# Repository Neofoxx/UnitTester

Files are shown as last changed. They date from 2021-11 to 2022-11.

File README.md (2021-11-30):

# UnitTester
A rack mounted piece of gear for testing chips

#### Why
Always wanted some rack-mount piece of gear based on the DIN 41612 standard. This is slightly modified.
Also, want to test the complete PIC32 toolchain without plugging and replugging the programmer a thousand times.

#### When
Soon.

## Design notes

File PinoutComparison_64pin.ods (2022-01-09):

Comparison of 64-pin PIC32s, that should (ideally) all fit on one board
Special features: |  |  | VCAP | 3v3 | GND | USB | ICSP | JTAG | ICSP+JTAG
Not shown – 5V tolerance of pins
PIN \ NAME | Common to all | PIC32MX170F512H | PIC32MX250F256H and PIC32MX570F512H | PIC32MX340F256H | PIC32MX440F256H | PIC32MX350F256H | PIC32MX450F256H | PIC32MX534F064H | PIC32MX675F256H | PIC32MX775F256H | PIC32MZ2048EFK064 (just checking)
1 |  | AN22/RPE5/PMD5/RE5 | AN22/RPE5/PMD5/RE5 | PMD5/RE5 | PMD5/RE5 | AN22/RPE5/PMD5/RE5 | AN22/RPE5/PMD5/RE5 | PMD5/RE5 | ETXEN/PMD5/RE5 | ETXEN/PMD5/RE5 | AN17/ETXEN/RPE5/PMD5/RE5
2 |  | AN23/PMD6/RE6 | AN23/PMD6/RE6 | PMD6/RE6 | PMD6/RE6 | AN23/PMD6/RE6 | AN23/PMD6/RE6 | PMD6/RE6 | ETXD0/PMD6/RE6 | ETXD0/PMD6/RE6 | AN16/ETXD0/PMD6/RE6
3 |  | AN27/PMD7/RE7 | AN27/PMD7/RE7 | PMD7/RE7 | PMD7/RE7 | AN27/PMD7/RE7 | AN27/PMD7/RE7 | PMD7/RE7 | ETXD1/PMD7/RE7 | ETXD1/PMD7/RE7 | AN15/ETXD1/PMD7/RE7
4 |  | AN16/C1IND/RPG6/SCK2/PMA5/RG6 | AN16/C1IND/RPG6/SCK2/PMA5/RG6 | SCK2/PMA5/CN8/RG6 | SCK2/PMA5/CN8/RG6 | AN16/C1IND/RPG6/SCK2/PMA5/RG6 | AN16/C1IND/RPG6/SCK2/PMA5/RG6 | SCK2/U6TX/U3RTS/PMA5/CN8/RG6 | SCK2/U6TX/U3RTS/PMA5/CN8/RG6 | SCK2/U6TX/U3RTS/PMA5/CN8/RG6 | AN14/C1IND/RPG6/SCK2/PMA5/RG6
5 |  | AN17/C1INC/RPG7/PMA4/RG7 | AN17/C1INC/RPG7/PMA4/RG7 | SDI2/PMA4/CN9/RG7 | SDI2/PMA4/CN9/RG7 | AN17/C1INC/RPG7/PMA4/RG7 | AN17/C1INC/RPG7/PMA4/RG7 | SDA4/SDI2/U3RX/PMA4/CN9/RG7 | SDA4/SDI2/U3RX/PMA4/CN9/RG7 | SDA4/SDI2/U3RX/PMA4/CN9/RG7 | AN13/C1INC/RPG7/SDA4/PMA4/RG7
6 |  | AN18/C2IND/RPG8/PMA3/RG8 | AN18/C2IND/RPG8/PMA3/RG8 | SDO2/PMA3/CN10/RG8 | SDO2/PMA3/CN10/RG8 | AN18/C2IND/RPG8/PMA3/RG8 | AN18/C2IND/RPG8/PMA3/RG8 | SCL4/SDO2/U3TX/PMA3/CN10/RG8 | SCL4/SDO2/U3TX/PMA3/CN10/RG8 | SCL4/SDO2/U3TX/PMA3/CN10/RG8 | AN12/C2IND/RPG8/SCL4/PM3/RG8
7 | MCLR | MCLR | MCLR | MCLR | MCLR | MCLR | MCLR | MCLR | MCLR | MCLR | VSS
8 |  | AN19/C2INC/RPG9/PMA2/RG9 | AN19/C2INC/RPG9/PMA2/RG9 | SS2/PMA2/CN11/RG9 | SS2/PMA2/CN11/RG9 | AN19/C2INC/RPG9/PMA2/RG9 | AN19/C2INC/RPG9/PMA2/RG9 | SS2 /U6RX/U3CTS/PMA2/CN11/RG9 | SS2/U6RX/U3CTS/PMA2/CN11/RG9 | SS2/U6RX/U3CTS/PMA2/CN11/RG9 | VDD
9 | VSS | VSS | VSS | VSS | VSS | VSS | VSS | VSS | VSS | VSS | MCLR
10 | VDD | VDD | VDD | VDD | VDD | VDD | VDD | VDD | VDD | VDD | AN11/C2INC/RPG9/PMA2/RG9
11 |  | AN5/C1INA/RPB5/RB5 | AN5/C1INA/RPB5/VBUSON/RB5 | AN5/C1IN+/CN7/RB5 | AN5/C1IN+/VBUSON/CN7/RB5 | AN5/C1INA/RPB5/RB5 | AN5/C1INA/RPB5/VBUSON/RB5 | AN5/C1IN+/VBUSON/CN7/RB5 | AN5/C1IN+/VBUSON/CN7/RB5 | AN5/C1IN+/VBUSON/CN7/RB5 | AN45/C1INA/RPB5/RB5
12 |  | AN4/C1INB/RB4 | AN4/C1INB/RB4 | AN4/C1IN-/CN6/RB4 | AN4/C1IN-/CN6/RB4 | AN4/C1INB/RB4 | AN4/C1INB/RB4 | AN4/C1IN-/CN6/RB4 | AN4/C1IN-/CN6/RB4 | AN4/C1IN-/CN6/RB4 | AN4/C1INB/RB4
13 |  | PGED3/AN3/C2INA/RPB3/RB3 | PGED3/AN3/C2INA/RPB3/RB3 | AN3/C2IN+/CN5/RB3 | AN3/C2IN+/CN5/RB3 | PGED3/AN3/C2INA/RPB3/RB3 | PGED3/AN3/C2INA/RPB3/RB3 | AN3/C2IN+/CN5/RB3 | AN3/C2IN+/CN5/RB3 | AN3/C2IN+/CN5/RB3 | AN3/C2INA/RPB3/RB3
14 |  | PGEC3/AN2/CTCMP/C2INB/RPB2/CTED13/RB2 | PGEC3/AN2/CTCMP/C2INB/RPB2/CTED13/RB2 | AN2/C2IN-/SS1/CN4/RB2 | AN2/C2IN-/CN4/RB2 | PGEC3/AN2/C2INB/RPB2/CTED13/RB2 | PGEC3/AN2/C2INB/RPB2/CTED13/RB2 | AN2/C2IN-/CN4/RB2 | AN2/C2IN-/CN4/RB2 | AN2/C2IN-/CN4/RB2 | AN2/C2INB/RPB2/RB2
15 |  | PGEC1/VREF-/AN1/RPB1/CTED12/RB1 | PGEC1/VREF-/AN1/RPB1/CTED12/RB1 | PGEC1/AN1/VREF-/CVREF-/CN3/RB1 | PGEC1/AN1/VREF-/CVREF-/CN3/RB1 | PGEC1/VREF-/CVREF-/AN1/RPB1/CTED12/RB1 | PGEC1/VREF-/CVREF-/AN1/RPB1/CTED12/RB1 | PGEC1/AN1/VREF-/CVREF-/CN3/RB1 | PGEC1/AN1/VREF-/CVREF-/CN3/RB1 | PGEC1/AN1/VREF-/CVREF-/CN3/RB1 | PGEC1/VREF-/CVREF-/AN1/RPB1/RB1
16 |  | PGED1/VREF+/AN0/RPB0/PMA6/RB0 | PGED1/VREF+/AN0/RPB0/PMA6/RB0 | PGED1/AN0/VREF+/CVREF+/PMA6/CN2/RB0 | PGED1/AN0/VREF+/CVREF+/PMA6/CN2/RB0 | PGED1/VREF+/CVREF+/AN0/RPB0/PMA6/RB0 | PGED1/VREF+/CVREF+/AN0/RPB0/PMA6/RB0 | PGED1/AN0/VREF+/CVREF+/PMA6/CN2/RB0 | PGED1/AN0/VREF+/CVREF+/PMA6/CN2/RB0 | PGED1/AN0/VREF+/CVREF+/PMA6/CN2/RB0 | PGED1/VREF+/CVREF+/AN0/RPB0/PMA6/RB0
17 | PGEC2 | PGEC2/AN6/RPB6/RB6 | PGEC2/AN6/RPB6/RB6 | PGEC2/AN6/OCFA/RB6 | PGEC2/AN6/OCFA/RB6 | PGEC2/AN6/RPB6/RB6 | PGEC2/AN6/RPB6/RB6 | PGEC2/AN6/OCFA/RB6 | PGEC2/AN6/OCFA/RB6 | PGEC2/AN6/OCFA/RB6 | PGEC2/AN46/RPB6/RB6
18 | PGED2 | PGED2/AN7/RPB7/CTED3/RB7 | PGED2/AN7/RPB7/CTED3/RB7 | PGED2/AN7/RB7 | PGED2/AN7/RB7 | PGED2/AN7/RPB7/CTED3//RB7 | PGED2/AN7/RPB7/CTED3//RB7 | PGED2/AN7/RB7 | PGED2/AN7/RB7 | PGED2/AN7/RB7 | PGED2/AN47/RPB7/RB7
19 | AVDD | AVDD | AVDD | AVDD | AVDD | AVDD | AVDD | AVDD | AVDD | AVDD | AVDD
20 | AVSS | AVSS | AVSS | AVSS | AVSS | AVSS | AVSS | AVSS | AVSS | AVSS | AVSS
21 |  | AN8/RPB8/CTED10/RB8 | AN8/RPB8/CTED10/RB8 | AN8/U2CTS/C1OUT/RB8 | AN8/U2CTS/C1OUT/RB8 | AN8/RPB8/CTED10//RB8 | AN8/RPB8/CTED10//RB8 | AN8/SS4/U5RX/U2CTS/C1OUT/RB8 | AN8/SS4/U5RX/U2CTS/C1OUT/RB8 | AN8/C2TX(2)/SS4/U5RX/U2CTS/C1OUT/RB8 | AN48/RPB8/PMA10/RB8
22 |  | AN9/RPB9/CTED4/PMA7/RB9 | AN9/RPB9/CTED4/PMA7/RB9 | AN9/C2OUT/PMA7/RB9 | AN9/C2OUT/PMA7/RB9 | AN9/RPB9/CTED4/PMA7/RB9 | AN9/RPB9/CTED4/PMA7/RB9 | AN9/C2OUT/PMA7/RB9 | AN9/C2OUT/PMA7/RB9 | AN9/C2OUT/PMA7/RB9 | AN49/RPB9/PMA7/RB9
23 | TMS | TMS/CVREFOUT/AN10/RPB10/CTED11/PMA13/RB10 | TMS/CVREFOUT/AN10/RPB10/CTED11/PMA13/RB10 | TMS/AN10/CVREFOUT/PMA13/RB10 | TMS/AN10/CVREFOUT/PMA13/RB10 | TMS/CVREFOUT/AN10/RPB10/CTED11//PMA13/RB10 | TMS/CVREFOUT/AN10/RPB10/CTED11//PMA13/RB10 | TMS/AN10/CVREFOUT/PMA13/RB10 | TMS/AN10/CVREFOUT/PMA13/RB10 | TMS/AN10/CVREFOUT/PMA13/RB10 | TMS/CVREFOUT/AN5/RPB10/PMA13/RB10
24 | TDO | TDO/AN11/PMA12/RB11 | TDO/AN11/PMA12/RB11 | TDO/AN11/PMA12/RB11 | TDO/AN11/PMA12//RB11 | TDO/AN11/PMA12/RB11 | TDO/AN11/PMA12/RB11 | TDO/AN11/PMA12/RB11 | TDO/AN11/PMA12/RB11 | TDO/AN11/PMA12/RB11 | TDO/AN6/PMA12/RB11
25 | VSS | VSS | VSS | VSS | VSS | VSS | VSS | VSS | VSS | VSS | VSS
26 | VDD | VDD | VDD | VDD | VDD | VDD | VDD | VDD | VDD | VDD | VDD
27 | TCK | TCK/AN12/PMA11/RB12 | TCK/AN12/PMA11/RB12 | TCK/AN12/PMA11/RB12 | TCK/AN12/PMA11/RB12 | TCK/AN12/PMA11/RB12 | TCK/AN12/PMA11/RB12 | TCK/AN12/PMA11/RB12 | TCK/AN12/PMA11/RB12 | TCK/AN12/PMA11/RB12 | TCK/AN7/PMA11/RB12
28 | TDI | TDI/AN13/PMA10/RB13 | TDI/AN13/PMA10/RB13 | TDI/AN13/PMA10/RB13 | TDI/AN13/PMA10/RB13 | TDI/AN13/PMA10/RB13 | TDI/AN13/PMA10/RB13 | TDI/AN13/PMA10/RB13 | TDI/AN13/PMA10/RB13 | TDI/AN13/PMA10/RB13 | TDI/AN8/RB13
29 |  | AN14/RPB14/SCK3/CTED5/PMA1/RB14 | AN14/RPB14/SCK3/CTED5/PMA1/RB14 | AN14/U2RTS/PMALH/PMA1/RB14 | AN14/U2RTS/PMALH/PMA1/RB14 | AN14/RPB14/CTED5/PMA1/RB14 | AN14/RPB14/CTED5/PMA1/RB14 | AN14/SCK4/U5TX/U2RTS/PMALH/PMA1/RB14 | AN14/SCK4/U5TX/U2RTS/PMALH/PMA1/RB14 6 | AN14/C2RX(2)/SCK4/U5TX/U2RTS/PMALH/PMA1/RB14 | AN9/RPB14/SCK3/PMA1/RB14
30 |  | AN15/RPB15/OCFB/CTED6/PMA0/RB15 | AN15/RPB15/OCFB/CTED6/PMA0/RB15 | AN15/OCFB/PMALL/PMA0/CN12/RB15 | AN15/OCFB/PMALL/PMA0/CN12/RB15 | AN15/RPB15/OCFB/CTED6/PMA0/RB15 | AN15/RPB15/OCFB/CTED6/PMA0/RB15 | AN15/OCFB/PMALL/PMA0/CN12/RB15 | AN15/EMDC/AEMDC/OCFB/PMALL/PMA0/CN12/RB15 | AN15/EMDC/AEMDC/OCFB/PMALL/PMA0/CN12/RB15 | AN10/EMDC/AEMDC/RPB15/OCFB/PMA0/RB15
31 | U2RX | RPF4/SDA2/PMA9/RF4 | RPF4/SDA2/PMA9/RF4 | SDA2/U2RX/PMA9/CN17/RF4 | SDA2/U2RX/PMA9/CN17/RF4 | RPF4/SDA2/PMA9/RF4 | RPF4/SDA2/PMA9/RF4 | AC1TX/SDA5/SDI4/U2RX/PMA9/CN17/RF4 | SDA5/SDI4/U2RX/PMA9/CN17/RF4 | AC1TX/SDA5/SDI4/U2RX/PMA9/CN17/RF4 | OSC1/CLKI/RC12
32 | U2TX | RPF5/SCL2/PMA8/RF5 | RPF5/SCL2/PMA8/RF5 | SCL2/U2TX/PMA8/CN18/RF5 | SCL2/U2TX/PMA8/CN18/RF5 | RPF5/SCL2/PMA8/RF5 | RPF5/SCL2/PMA8/RF5 | AC1RX/SCL5/SDO4/U2TX/PMA8/CN18/RF5 | SCL5/SDO4/U2TX/PMA8/CN18/RF5 | AC1RX/SCL5/SDO4/U2TX/PMA8/CN18/RF5 | OSC2/CLKO/RC15
33 |  | RPF3/RF3 | USBID/RPF3/RF3 | U1TX/SDO1/RF3 | USBID/RF3 | RPF3/RF3 | USBID/RF3 | USBID/RF3 | USBID/RF3 | USBID/RF3 | VBUS
34 | 5V VIA VOLTAGE DIVIDER | RPF2/RF2 | VBUS | U1RX/SDI1/RF2 | VBUS | RPF2/RF2 | VBUS | VBUS | VBUS | VBUS | VUSB3V3
35 | VDD VIA RESISTOR | RPF6/SCK1/INT0/RF6 | VUSB3V3 | U1RTS/SCK1/INT0/RF6 | VUSB | RPF6/SCK1/INT0/RF6 | VUSB3V3 | VUSB3V3 | VUSB3V3 | VUSB3V3 | VSS
36 | D- | SDA1/RG3 | D- | SDA1/RG3 | D-/RG3 | SDA1/RG3 | D- | D-/RG3 | D-/RG3 | D-/RG3 | D-
37 | D+ | SCL1/RG2 | D+ | SCL1/RG2 | D+/RG2 | SCL1/RG2 | D+ | D+/RG2 | D+/RG2 | D+/RG2 | D+
38 | VDD | VDD | VDD | VDD | VDD | VDD | VDD | VDD | VDD | VDD | RPF3/USBID/RF3
39 | Crystal | OSC1/CLKI/RC12 | OSC1/CLKI/RC12 | OSC1/CLKI/RC12 | OSC1/CLKI/RC12 | OSC1/CLKI/RC12 | OSC1/CLKI/RC12 | OSC1/CLKI/RC12 | OSC1/CLKI/RC12 | OSC1/CLKI/RC12 | VDD
40 | Crystal | OSC2/CLKO/RC15 | OSC2/CLKO/RC15 | OSC2/CLKO/RC15 | OSC2/CLKO/RC15 | OSC2/CLKO/RC15 | OSC2/CLKO/RC15 | OSC2/CLKO/RC15 | OSC2/CLKO/RC15 | OSC2/CLKO/RC15 | VSS
41 | VSS | VSS | VSS | VSS | VSS | VSS | VSS | VSS | VSS | VSS | RPF4/SDA5/PMA9/RF4
42 |  | RPD8/RTCC/RD8 | RPD8/RTCC/RD8 | RTCC/IC1/INT1/RD8 | RTCC/IC1/INT1/RD8 | RPD8/RTCC/RD8 | RPD8/RTCC/RD8 | RTCC/IC1/INT1/RD8 | RTCC/AERXD1/ETXD3/IC1/INT1/RD8 | RTCC/AERXD1/ETXD3/IC1/INT1/RD8 | RPF5/SCL5/PMA8/RF5
43 |  | RPD9/RD9 | RPD9/SDA1/RD9 | U1CTS/IC2/INT2/RD9 | U1CTS/SDA1/IC2/INT2/RD9 | RPD9/RD9 | RPD9/SDA1/RD9 | SS3/U4RX/U1CTS/SDA1/IC2/INT2/RD9 | AERXD0/ETXD2/SS3/U4RX/U1CTS/SDA1/IC2/INT2/RD9 | AERXD0/ETXD2/SS3/U4RX/U1CTS/SDA1/IC2/INT2/RD9 | AERXD0/ETXD2/RPD9/SDA1/PMCS2/PMA15/RD9
44 |  | RPD10/PMA15/RD10 | RPD10/SCL1/PMA15/RD10 | IC3/PMCS2/PMA15/INT3/RD10 | SCL1/IC3/PMCS2/PMA15/INT3/RD10 | RPD10/PMCS2/RD10 | RPD10/SCL1/PMCS2/RD10 | SCL1/IC3/PMCS2/PMA15/INT3/RD10 | ECOL/AECRSDV/SCL1/IC3/PMCS2/PMA15/INT3/RD10 | ECOL/AECRSDV/SCL1/IC3/PMCS2/PMA15/INT3/RD10 | ECOL/RPD10/SCL1/SCK4/RD10
45 |  | RPD11/PMA14/RD11 | RPD11/PMA14/RD11 | IC4/PMCS1/PMA14/INT4/RD11 | IC4/PMCS1/PMA14/INT4/RD11 | RPD11/PMCS1/RD11 | RPD11/PMCS1/RD11 | IC4/PMCS1/PMA14/INT4/RD11 | ECRS/AEREFCLK/IC4/PMCS1/PMA14/INT4/RD11 | ECRS/AEREFCLK/IC4/PMCS1/PMA14/INT4/RD11 | AERXCLK/AEREFCLK/ECRS/RPD11/PMCS1/PMA14/RD11
46 | LED | RPD0/RD0 | RPD0/INT0/RD0 | OC1/RD0 | OC1/INT0/RD0 | RPD0/RD0 | RPD0/INT0/RD0 | OC1/INT0/RD0 | OC1/INT0/RD0 | OC1/INT0/RD0 | AERXD1/ETXD3/RPD0/RTCC/INT0/RD0
47 | Crystal | SOSCI/RPC13/RC13 | SOSCI/RPC13/RC13 | SOSCI/CN1/RC13 | SOSCI/CN1/RC13 | SOSCI/RPC13/RC13 | SOSCI/RPC13/RC13 | SOSCI/CN1/RC13 | SOSCI/CN1/RC13 | SOSCI/CN1/RC13 | SOSCI/RPC13/RC13
48 | Crystal | SOSCO/RPC14/T1CK/RC14 | SOSCO/RPC14/T1CK/RC14 | SOSCO/T1CK/CN0/RC14 | SOSCO/T1CK/CN0/RC14 | SOSCO/RPC14/T1CK/RC14 | SOSCO/RPC14/T1CK/RC14 | SOSCO/T1CK/CN0/RC14 | SOSCO/T1CK/CN0/RC14 | SOSCO/T1CK/CN0/RC14 | SOSCO/RPC14/T1CK/RC14
49 |  | AN24/RPD1/RD1 | AN24/RPD1/RD1 | OC2/RD1 | U1RTS/OC2/RD1 | AN24/RPD1/RD1 | AN24/RPD1/RD1 | SCK3/U4TX/U1RTS/OC2/RD1 | EMDIO/AEMDIO/SCK3/U4TX/U1RTS/OC2/RD1 | EMDIO/AEMDIO/SCK3/U4TX/U1RTS/OC2/RD1 | EMDIO/AEMDIO/RPD1/SCK1/RD1
50 |  | AN25/RPD2/RD2 | AN25/RPD2/SCK1/RD2 | OC3/RD2 | U1RX/OC3/RD2 | AN25/RPD2/RD2 | AN25/RPD2/SCK1/RD2 | SDA3/SDI3/U1RX/OC3/RD2 | SDA3/SDI3/U1RX/OC3/RD2 | SDA3/SDI3/U1RX/OC3/RD2 | ETXERR/AETXEN/RPD2/SDA3/RD2
51 |  | AN26/C3IND/RPD3/RD3 | AN26/C3IND/RPD3/RD3 | OC4/RD3 | U1TX/OC4/RD3 | AN26/RPD3/RD3 | AN26/RPD3/RD3 | SCL3/SDO3/U1TX/OC4/RD3 | SCL3/SDO3/U1TX/OC4/RD3 | SCL3/SDO3/U1TX/OC4/RD3 | AERXERR/ETXCLK/RPD3/SCL3/RD3
52 | BUTTON | RPD4/PMWR/RD4 | RPD4/PMWR/RD4 | OC5/IC5/PMWR/CN13/RD4 | OC5/IC5/PMWR/CN13/RD4 | RPD4/PMWR/RD4 | RPD4/PMWR/RD4 | OC5/IC5/PMWR/CN13/RD4 | OC5/IC5/PMWR/CN13/RD4 | OC5/IC5/PMWR/CN13/RD4 | SQICS0/RPD4/PMWR/RD4
53 |  | RPD5/PMRD/RD5 | RPD5/PMRD/RD5 | PMRD/CN14/RD5 | PMRD/CN14/RD5 | RPD5/PMRD/RD5 | RPD5/PMRD/RD5 | PMRD/CN14/RD5 | PMRD/CN14/RD5 | PMRD/CN14/RD5 | SQICS1/RPD5/PMRD/RD5
54 |  | C3INC/RD6 | C3INC/RD6 | CN15/RD6 | CN15/RD6 | RD6 | RD6 | CN15/RD6 | AETXEN/ETXERR/CN15/RD6 | AETXEN/ETXERR/CN15/RD6 | VDD
55 |  | C3INB/RD7 | C3INB/RD7 | CN16/RD7 | CN16/RD7 | RD7 | RD7 | CN16/RD7 | ETXCLK/AERXERR/CN16/RD7 | ETXCLK/AERXERR/CN16/RD7 | VSS
56 | VCAP | VCAP | VCAP | VCAP/VCORE | VCAP/VCORE | VCAP | VCAP | VCAP | VCAP | VCAP | ERXD3/AETXD1/RPF0/RF0
57 | VDD | VDD | VDD | ENVREG | ENVREG | VDD | VDD | VDD | VDD | VDD | TRCLK/SQICLK/ERXD2/AETXD0/RPF1/RF1
58 |  | C3INA/RPF0/RF0 | C3INA/RPF0/RF0 | RF0 | RF0 | RPF0/RF0 | RPF0/RF0 | C1RX/RF0 | AETXD1/ERXD3/RF0 | C1RX/AETXD1/ERXD3/RF0 | TRD0/SQID0/ERXD1/PMD0/RE0
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

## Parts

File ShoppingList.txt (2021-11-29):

- PIC12F615, HV verzija (vsaj 8, SOIC)
- Refill kondenzatorjev

* PIC32MX274F256D (PIC32MX275F256D is not available (with VBAT), MX175 ditto)

* = variants with USB
+ = variants with CAN
Support list
* PIC32MM GPL - done

* PIC32MM GPM - done

* PIC32MX 1/2*/5+
-> PIC32MX 1/2 should be done
-> PIC32MX 5 should be done, was tested with a little gumstix board from mikroelektronika

* PIC32MX 1/2* XLP - NOT DONE, NOT TESTED

* PIC32MX 3/4*
- Should be done, but there are some differences between say 340 and 350.
- Warrants another look

* PIC32MX 5x/6*/7+ (yo wtf) - shold be done
- Series 6&7 weren't tested, 5 should be in the above

* PIC32MK GP/MC
- Work continuing on it. There are differences in chips, but the peripherals are the same
- Differences are dual-banks of flash for example.

* PIC32MZ EF
- Should be working

* PIC32MZ DA
- Never tried, TODO

* PIC32MZ EC
- The abandoned platform. Purely out fo jest we should support it

* PIC32W (EZ in disguise)
- Should make compile just because.

Needed chips are then
MX5, MX6, MX7, MX1/2 XLP, MK?, MZ DA, MZ EC, MZ W.

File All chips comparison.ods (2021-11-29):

No. | Family | Part name | Pins | Package | Boot flash (kB) | Flash (kB) | RAM (kB) | Supported by toolchain | Debugging? | Own? | Notes
1 | PIC32MM GPL | PIC32MM0016GPL020 | 20 | SSOP/QFN | 5.75 | 16 | 4 | YES (needs procdefs) | NO |  | GPL family is fully supported
2 | PIC32MM GPL | PIC32MM0032GPL020 | 20 | SSOP/QFN | 5.75 | 32 | 8 | YES (needs procdefs) | NO
3 | PIC32MM GPL | PIC32MM0064GPL020 | 20 | SSOP/QFN | 5.75 | 64 | 8 | YES (needs procdefs) | NO | YES
4 | PIC32MM GPL | PIC32MM0016GPL028 | 28 | SSOP/SOIC/QFN/UQFN | 5.75 | 16 | 4 | YES (needs procdefs) | NO
5 | PIC32MM GPL | PIC32MM0032GPL028 | 28 | SSOP/SOIC/QFN/UQFN | 5.75 | 32 | 8 | YES (needs procdefs) | NO
6 | PIC32MM GPL | PIC32MM0064GPL028 | 28 | SSOP/SOIC/QFN/UQFN | 5.75 | 64 | 8 | YES (needs procdefs) | NO | YES
7 | PIC32MM GPL | PIC32MM0016GPL036 | 36/40 | VQFN/UQFN | 5.75 | 16 | 4 | YES (needs procdefs) | NO |  | 36-pin and 40-pin variants….
8 | PIC32MM GPL | PIC32MM0032GPL036 | 36/40 | VQFN/UQFN | 5.75 | 32 | 8 | YES (needs procdefs) | NO |  | 36-pin and 40-pin variants….
9 | PIC32MM GPL | PIC32MM0064GPL036 | 36/40 | VQFN/UQFN | 5.75 | 64 | 8 | YES | NO | YES | 36-pin and 40-pin variants….
10 | PIC32MM GPM | PIC32MM0064GPM028 | 28 | SSOP/QFN/UQFN | 5.75 | 64 | 16 | YES (needs procdefs) | NO |  | GPM family is fully supported
11 | PIC32MM GPM | PIC32MM0128GPM028 | 28 | SSOP/QFN/UQFN | 5.75 | 128 | 16 | YES (needs procdefs) | NO
12 | PIC32MM GPM | PIC32MM0256GPM028 | 28 | SSOP/QFN/UQFN | 5.75 | 256 | 32 | YES (needs procdefs) | NO | YES
13 | PIC32MM GPM | PIC32MM0064GPM036 | 36/40 | VQFN/UQFN | 5.75 | 64 | 16 | YES (needs procdefs) | NO |  | 36-pin and 40-pin variants….
14 | PIC32MM GPM | PIC32MM0128GPM036 | 36/40 | VQFN/UQFN | 5.75 | 128 | 16 | YES (needs procdefs) | NO |  | 36-pin and 40-pin variants….
15 | PIC32MM GPM | PIC32MM0256GPM036 | 36/40 | VQFN/UQFN | 5.75 | 256 | 32 | YES (needs procdefs) | NO | YES | 36-pin and 40-pin variants….
16 | PIC32MM GPM | PIC32MM0064GPM048 | 48 | UQFN/TQFP | 5.75 | 64 | 16 | YES (needs procdefs) | NO
17 | PIC32MM GPM | PIC32MM0128GPM048 | 48 | UQFN/TQFP | 5.75 | 128 | 16 | YES (needs procdefs) | NO
18 | PIC32MM GPM | PIC32MM0256GPM048 | 48 | UQFN/TQFP | 5.75 | 256 | 32 | YES (needs procdefs) | NO
19 | PIC32MM GPM | PIC32MM0064GPM064 | 64 | QFN/TQFP | 5.75 | 64 | 16 | YES (needs procdefs) | NO
20 | PIC32MM GPM | PIC32MM0128GPM064 | 64 | QFN/TQFP | 5.75 | 128 | 16 | YES (needs procdefs) | NO
21 | PIC32MM GPM | PIC32MM0256GPM064 | 64 | QFN/TQFP | 5.75 | 256 | 32 | YES (needs procdefs) | NO
22 | PIC32MX 1 | PIC32MX110F016B | 28 | SOIC,SSOP,SPDIP,QFN | 3 | 16 | 4 | YES (needs procdefs) | YES |  | PIC32MX 1 == PIC32MX 2, just without USB
23 | PIC32MX 1 | PIC32MX110F016C | 36 | VTLA | 3 | 16 | 4 | YES (needs procdefs) | YES
24 | PIC32MX 1 | PIC32MX110F016D | 44 | VTLA,TQFP,QFN | 3 | 16 | 4 | YES (needs procdefs) | YES
25 | PIC32MX 1 | PIC32MX120F032B | 28 | SOIC,SSOP,SPDIP,QFN | 3 | 32 | 8 | YES (needs procdefs) | YES
26 | PIC32MX 1 | PIC32MX120F032C | 36 | VTLA | 3 | 32 | 8 | YES (needs procdefs) | YES
27 | PIC32MX 1 | PIC32MX120F032D | 44 | VTLA,TQFP,QFN | 3 | 32 | 8 | YES (needs procdefs) | YES
28 | PIC32MX 1 | PIC32MX130F064B | 28 | SOIC,SSOP,SPDIP,QFN | 3 | 64 | 16 | YES (needs procdefs) | YES
29 | PIC32MX 1 | PIC32MX130F064C | 36 | VTLA | 3 | 64 | 16 | YES (needs procdefs) | YES
30 | PIC32MX 1 | PIC32MX130F064D | 44 | VTLA,TQFP,QFN | 3 | 64 | 16 | YES (needs procdefs) | YES
31 | PIC32MX 1 | PIC32MX150F128B | 28 | SOIC,SSOP,SPDIP,QFN | 3 | 128 | 32 | YES (needs procdefs) | YES
32 | PIC32MX 1 | PIC32MX150F128C | 36 | VTLA | 3 | 128 | 32 | YES (needs procdefs) | YES
33 | PIC32MX 1 | PIC32MX150F128D | 44 | VTLA,TQFP,QFN | 3 | 128 | 32 | YES (needs procdefs) | YES
34 | PIC32MX 1 | PIC32MX130F256B | 28 | SSOP,SPDIP,QFN | 3 | 256 | 16 | YES (needs procdefs) | YES
35 | PIC32MX 1 | PIC32MX130F256D | 44 | VTLA,TQFP,QFN | 3 | 256 | 16 | YES (needs procdefs) | YES
36 | PIC32MX 1 | PIC32MX170F256B | 28 | SOIC,SSOP,SPDIP,QFN | 3 | 256 | 64 | YES (needs procdefs) | YES
37 | PIC32MX 1 | PIC32MX170F256D | 44 | VTLA,TQFP,QFN | 3 | 256 | 64 | YES (needs procdefs) | YES | Ordered
38 | PIC32MX1/2/5 | PIC32MX120F064H | 64 | QFN,TQFP | 3 | 64 | 8 | PROBABLY (needs procdefs) | YES |  | High pin-count versions of MX1/2 ?
39 | PIC32MX1/2/5 | PIC32MX130F128H | 64 | QFN,TQFP | 3 | 128 | 16 | PROBABLY (needs procdefs) | YES
40 | PIC32MX1/2/5 | PIC32MX130F128L | 100 | TQFP | 3 | 128 | 16 | PROBABLY (needs procdefs) | YES
41 | PIC32MX1/2/5 | PIC32MX150F256H | 64 | QFN,TQFP | 3 | 256 | 32 | PROBABLY (needs procdefs) | YES
42 | PIC32MX1/2/5 | PIC32MX150F256L | 100 | TQFP | 3 | 256 | 32 | PROBABLY (needs procdefs) | YES
43 | PIC32MX1/2/5 | PIC32MX170F512H | 64 | QFN,TQFP | 3 | 512 | 64 | PROBABLY (needs procdefs) | YES | Ordered
44 | PIC32MX1/2/5 | PIC32MX170F512L | 100 | TQFP,TFBGA | 3 | 512 | 64 | PROBABLY (needs procdefs) | YES
45 | PIC32MX 2 | PIC32MX210F016B | 28 | SOIC,SSOP,SPDIP,QFN | 3 | 16 | 4 | YES (needs procdefs) | YES
46 | PIC32MX 2 | PIC32MX210F016C | 36 | VTLA | 3 | 16 | 4 | YES (needs procdefs) | YES
47 | PIC32MX 2 | PIC32MX210F016D | 44 | VTLA,TQFP,QFN | 3 | 16 | 4 | YES (needs procdefs) | YES
48 | PIC32MX 2 | PIC32MX220F032B | 28 | SOIC,SSOP,SPDIP,QFN | 3 | 32 | 8 | YES (needs procdefs) | YES
49 | PIC32MX 2 | PIC32MX220F032C | 36 | VTLA | 3 | 32 | 8 | YES (needs procdefs) | YES
50 | PIC32MX 2 | PIC32MX220F032D | 44 | VTLA,TQFP,QFN | 3 | 32 | 8 | YES (needs procdefs) | YES
51 | PIC32MX 2 | PIC32MX230F064B | 28 | SOIC,SSOP,SPDIP,QFN | 3 | 64 | 16 | YES (needs procdefs) | YES
52 | PIC32MX 2 | PIC32MX230F064C | 36 | VTLA | 3 | 64 | 16 | YES (needs procdefs) | YES
53 | PIC32MX 2 | PIC32MX230F064D | 44 | VTLA,TQFP,QFN | 3 | 64 | 16 | YES (needs procdefs) | YES
54 | PIC32MX 2 | PIC32MX250F128B | 28 | SOIC,SSOP,SPDIP,QFN | 3 | 128 | 32 | YES | YES | YES
55 | PIC32MX 2 | PIC32MX250F128C | 36 | VTLA | 3 | 128 | 32 | YES (needs procdefs) | YES
56 | PIC32MX 2 | PIC32MX250F128D | 44 | VTLA,TQFP,QFN | 3 | 128 | 32 | YES (needs procdefs) | YES
57 | PIC32MX 2 | PIC32MX230F256B | 28 | SSOP,SPDIP,QFN | 3 | 256 | 64 | YES (needs procdefs) | YES
58 | PIC32MX 2 | PIC32MX230F256D | 44 | VTLA,TQFP,QFN | 3 | 256 | 64 | YES (needs procdefs) | YES
59 | PIC32MX 2 | PIC32MX270F256B | 28 | SOIC,SSOP,SPDIP,QFN | 3 | 256 | 64 | YES (needs procdefs) | YES |  | Most powerful controller in DIP
60 | PIC32MX 2 | PIC32MX270F256D | 44 | VTLA,TQFP,QFN | 3 | 256 | 64 | YES | YES | YES
61 | PIC32MX1/2/5 | PIC32MX230F128H | 64 | QFN,TQFP | 3 | 128 | 16 | PROBABLY (needs procdefs) | YES |  | '== MX 1 + USB
62 | PIC32MX1/2/5 | PIC32MX230F128L | 100 | TQFP | 3 | 128 | 16 | PROBABLY (needs procdefs) | YES
63 | PIC32MX1/2/5 | PIC32MX250F256H | 64 | QFN,TQFP | 3 | 256 | 32 | PROBABLY (needs procdefs) | YES | Ordered
64 | PIC32MX1/2/5 | PIC32MX250F256L | 100 | TQFP | 3 | 256 | 32 | PROBABLY (needs procdefs) | YES
65 | PIC32MX1/2/5 | PIC32MX270F512H | 64 | QFN,TQFP | 3 | 512 | 64 | PROBABLY (needs procdefs) | YES
66 | PIC32MX1/2/5 | PIC32MX270F512L | 100 | TQFP,TFBGA | 3 | 512 | 64 | PROBABLY (needs procdefs) | YES
67 | PIC32MX 3 (320) | PIC32MX320F032H | 64 | TQFP,QFN | 12 | 32 | 8 | YES (needs procdefs) | YES |  | PIC32MX 320/340/360/420/440/460 are their own group
68 | PIC32MX 3 (320) | PIC32MX320F064H | 64 | TQFP,QFN | 12 | 64 | 16 | YES (needs procdefs) | YES |  | PIC32MX 330/350/370/430/450/470 are their own group
69 | PIC32MX 3 (320) | PIC32MX320F128H | 64 | TQFP,QFN | 12 | 128 | 16 | YES (needs procdefs) | YES |  | The 320 group is pin-compatible to dsPIC devices, apparently
70 | PIC32MX 3 (320) | PIC32MX340F128H | 64 | TQFP,QFN | 12 | 128 | 32 | YES (needs procdefs) | YES |  | 3 == 4 without USB
71 | PIC32MX 3 (320) | PIC32MX340F256H | 64 | TQFP,QFN | 12 | 256 | 32 | YES (needs procdefs) | YES | Ordered
72 | PIC32MX 3 (320) | PIC32MX340F512H | 64 | TQFP,QFN | 12 | 512 | 32 | YES (needs procdefs) | YES
73 | PIC32MX 3 (320) | PIC32MX320F128L | 100/121 | TQFP,BGA | 12 | 128 | 16 | YES (needs procdefs) | YES
74 | PIC32MX 3 (320) | PIC32MX340F128L | 100/121 | TQFP,BGA | 12 | 128 | 32 | YES (needs procdefs) | YES
75 | PIC32MX 3 (320) | PIC32MX360F256L | 100/121 | TQFP,BGA | 12 | 256 | 32 | YES (needs procdefs) | YES
76 | PIC32MX 3 (320) | PIC32MX360F512L | 100/121 | TQFP,BGA | 12 | 512 | 32 | YES (needs procdefs) | YES
77 | PIC32MX 4 (320) | PIC32MX420F032H | 64 | TQFP,QFN | 12 | 32 | 8 | YES (needs procdefs) | YES
78 | PIC32MX 4 (320) | PIC32MX440F128H | 64 | TQFP,QFN | 12 | 128 | 32 | YES (needs procdefs) | YES
79 | PIC32MX 4 (320) | PIC32MX440F256H | 64 | TQFP,QFN | 12 | 256 | 32 | YES | YES | Ordered
80 | PIC32MX 4 (320) | PIC32MX440F512H | 64 | TQFP,QFN | 12 | 512 | 32 | YES (needs procdefs) | YES
81 | PIC32MX 4 (320) | PIC32MX440F128L | 100/121 | TQFP,BGA | 12 | 128 | 32 | YES (needs procdefs) | YES
82 | PIC32MX 4 (320) | PIC32MX460F256L | 100/121 | TQFP,BGA | 12 | 256 | 32 | YES (needs procdefs) | YES
83 | PIC32MX 4 (320) | PIC32MX460F512L | 100/121 | TQFP,BGA | 12 | 512 | 32 | YES (needs procdefs) | YES
84 | PIC32MX 3 (330) | PIC32MX330F064H | 64 | QFN,TQFP | 12 | 64 | 16 | PROBABLY (needs procdefs) | YES
85 | PIC32MX 3 (330) | PIC32MX330F064L | 100/124 | TQFP,VTLA | 12 | 64 | 16 | PROBABLY (needs procdefs) | YES
86 | PIC32MX 3 (330) | PIC32MX350F128H | 64 | QFN,TQFP | 12 | 128 | 32 | PROBABLY (needs procdefs) | YES
87 | PIC32MX 3 (330) | PIC32MX350F128L | 100/124 | TQFP,VTLA | 12 | 128 | 32 | PROBABLY (needs procdefs) | YES
88 | PIC32MX 3 (330) | PIC32MX350F256H | 64 | QFN,TQFP | 12 | 256 | 64 | PROBABLY (needs procdefs) | YES | Ordered
89 | PIC32MX 3 (330) | PIC32MX350F256L | 100/124 | TQFP,VTLA | 12 | 256 | 64 | PROBABLY (needs procdefs) | YES
90 | PIC32MX 3 (330) | PIC32MX370F512H | 64 | QFN,TQFP | 12 | 512 | 128 | PROBABLY (needs procdefs) | YES
91 | PIC32MX 3 (330) | PIC32MX370F512L | 100/124 | TQFP,VTLA | 12 | 512 | 128 | PROBABLY (needs procdefs) | YES
92 | PIC32MX 4 (330) | PIC32MX430F064H | 64 | QFN,TQFP | 12 | 64 | 16 | PROBABLY (needs procdefs) | YES
93 | PIC32MX 4 (330) | PIC32MX430F064L | 100/124 | TQFP,VTLA | 12 | 64 | 16 | PROBABLY (needs procdefs) | YES
94 | PIC32MX 4 (330) | PIC32MX450F128H | 64 | QFN,TQFP | 12 | 128 | 32 | PROBABLY (needs procdefs) | YES
95 | PIC32MX 4 (330) | PIC32MX450F128L | 100/124 | TQFP,VTLA | 12 | 128 | 32 | PROBABLY (needs procdefs) | YES
96 | PIC32MX 4 (330) | PIC32MX450F256H | 64 | QFN,TQFP | 12 | 256 | 64 | PROBABLY (needs procdefs) | YES | Ordered
97 | PIC32MX 4 (330) | PIC32MX450F256L | 100/124 | TQFP,VTLA | 12 | 256 | 64 | PROBABLY (needs procdefs) | YES
98 | PIC32MX 4 (330) | PIC32MX470F512H | 64 | QFN,TQFP | 12 | 512 | 128 | PROBABLY (needs procdefs) | YES
99 | PIC32MX 4 (330) | PIC32MX470F512L | 100/124 | TQFP,VTLA | 12 | 512 | 128 | PROBABLY (needs procdefs) | YES
100 | PIC32MX1/2/5 | PIC32MX530F128H | 64 | QFN,TQFP | 3 | 128 | 16 | PROBABLY (needs procdefs) | YES |  | ' == MX2 + CAN (MX1 + USB + CAN)
101 | PIC32MX1/2/5 | PIC32MX530F128L | 100 | TQFP | 3 | 128 | 16 | PROBABLY (needs procdefs) | YES
102 | PIC32MX1/2/5 | PIC32MX550F256H | 64 | QFN,TQFP | 3 | 256 | 32 | PROBABLY (needs procdefs) | YES
103 | PIC32MX1/2/5 | PIC32MX550F256L | 100 | TQFP | 3 | 256 | 32 | PROBABLY (needs procdefs) | YES
104 | PIC32MX1/2/5 | PIC32MX570F512H | 64 | QFN,TQFP | 3 | 512 | 64 | PROBABLY (needs procdefs) | YES | Ordered
105 | PIC32MX1/2/5 | PIC32MX570F512L | 100 | TQFP,TFBGA | 3 | 512 | 64 | PROBABLY (needs procdefs) | YES
106 | PIC32MX 5 | PIC32MX534F064H | 64 | TQFP,QFN | 12 | 64 | 16 | YES (needs procdefs) | YES | Ordered | MX5 is USB + CAN
107 | PIC32MX 5 | PIC32MX564F064H | 64 | TQFP,QFN | 12 | 64 | 32 | YES (needs procdefs) | YES
108 | PIC32MX 5 | PIC32MX564F128H | 64 | TQFP,QFN | 12 | 128 | 32 | YES (needs procdefs) | YES | YES (QuadUart)
109 | PIC32MX 5 | PIC32MX575F256H | 64 | TQFP,QFN | 12 | 256 | 64 | YES (needs procdefs) | YES
110 | PIC32MX 5 | PIC32MX575F512H | 64 | TQFP,QFN | 12 | 512 | 64 | YES (needs procdefs) | YES
111 | PIC32MX 5 | PIC32MX534F064L | 100 | TQFP,TFBGA | 12 | 64 | 16 | YES (needs procdefs) | YES
112 | PIC32MX 5 | PIC32MX564F064L | 100 | TQFP,TFBGA | 12 | 64 | 32 | YES (needs procdefs) | YES
113 | PIC32MX 5 | PIC32MX564F128L | 100 | TQFP,TFBGA | 12 | 128 | 32 | YES (needs procdefs) | YES
114 | PIC32MX 5 | PIC32MX575F256L | 100 | TQFP,TFBGA | 12 | 256 | 64 | YES (needs procdefs) | YES
115 | PIC32MX 5 | PIC32MX575F512L | 100 | TQFP,TFBGA | 12 | 512 | 64 | YES (needs procdefs) | YES
116 | PIC32MX 6 | PIC32MX664F064H | 64 | TQFP,QFN | 12 | 64 | 32 |  |  |  | MX6 is USB + ETHERNET
117 | PIC32MX 6 | PIC32MX664F128H | 64 | TQFP,QFN | 12 | 128 | 32 | YES (needs procdefs) | YES
118 | PIC32MX 6 | PIC32MX675F256H | 64 | TQFP,QFN | 12 | 256 | 64 | YES (needs procdefs) | YES | Ordered
119 | PIC32MX 6 | PIC32MX675F512H | 64 | TQFP,QFN | 12 | 512 | 64 | YES (needs procdefs) | YES
120 | PIC32MX 6 | PIC32MX695F512H | 64 | TQFP,QFN | 12 | 512 | 128 | YES (needs procdefs) | YES
121 | PIC32MX 6 | PIC32MX664F064L | 100 | TQFP,TFBGA | 12 | 64 | 32 | YES (needs procdefs) | YES
122 | PIC32MX 6 | PIC32MX664F128L | 100 | TQFP,TFBGA | 12 | 128 | 32 | YES (needs procdefs) | YES
123 | PIC32MX 6 | PIC32MX675F256L | 100 | TQFP,TFBGA | 12 | 256 | 64 | YES (needs procdefs) | YES
124 | PIC32MX 6 | PIC32MX675F512L | 100 | TQFP,TFBGA,VTLA | 12 | 512 | 64 | YES (needs procdefs) | YES
125 | PIC32MX 6 | PIC32MX695F512L | 100 | TQFP,TFBGA,VTLA | 12 | 512 | 128 | YES (needs procdefs) | YES
126 | PIC32MX 7 | PIC32MX764F128H | 64 | TQFP,QFN | 12 | 128 | 32 | YES (needs procdefs) | YES |  | MX7 is USB + ETHERNET + CAN
127 | PIC32MX 7 | PIC32MX775F256H | 64 | TQFP,QFN | 12 | 256 | 64 | YES (needs procdefs) | YES | Ordered
128 | PIC32MX 7 | PIC32MX775F512H | 64 | TQFP,QFN | 12 | 512 | 64 | YES (needs procdefs) | YES
129 | PIC32MX 7 | PIC32MX795F512H | 64 | TQFP,QFN | 12 | 512 | 128 | YES (needs procdefs) | YES
130 | PIC32MX 7 | PIC32MX764F128L | 100 | TQFP,TFBGA | 12 | 128 | 32 | YES (needs procdefs) | YES
131 | PIC32MX 7 | PIC32MX775F256L | 100 | TQFP,TFBGA | 12 | 256 | 64 | YES (needs procdefs) | YES
132 | PIC32MX 7 | PIC32MX775F512L | 100 | TQFP,TFBGA | 12 | 512 | 64 | YES (needs procdefs) | YES
133 | PIC32MX 7 | PIC32MX795F512L | 100 | TQFP,TFBGA,VTLA | 12 | 512 | 128 | YES (needs procdefs) | YES
134 | PIC32MX 1 XLP | PIC32MX154F128B | 28 | SOIC,QFN | 12 | 128 | 32 | PROBABLY (needs procdefs) | YES
135 | PIC32MX 1 XLP | PIC32MX154F128D | 44 | TQFP,QFN | 12 | 128 | 32 | PROBABLY (needs procdefs) | YES
136 | PIC32MX 1 XLP | PIC32MX174F256B | 28 | SOIC,QFN | 12 | 256 | 64 | PROBABLY (needs procdefs) | YES | Ordered
137 | PIC32MX 1 XLP | PIC32MX174F256D | 44 | TQFP,QFN | 12 | 256 | 64 | PROBABLY (needs procdefs) | YES
138 | PIC32MX 2 XLP | PIC32MX254F128B | 28 | SOIC,QFN | 12 | 128 | 32 | PROBABLY (needs procdefs) | YES |  | MX2 XLP is MX1 XLP + USB
139 | PIC32MX 2 XLP | PIC32MX254F128D | 44 | TQFP,QFN | 12 | 128 | 32 | PROBABLY (needs procdefs) | YES
140 | PIC32MX 2 XLP | PIC32MX274F256B | 28 | SOIC,QFN | 12 | 256 | 64 | PROBABLY (needs procdefs) | YES
141 | PIC32MX 2 XLP | PIC32MX274F256D | 44 | TQFP,QFN | 12 | 256 | 64 | PROBABLY (needs procdefs) | YES | Ordered
142 | PIC32MZ EF | PIC32MZ0512EFE064 | 64 | TQFP,QFN | 160 | 512 | 128 | YES (needs procdefs) | NO |  | // E/G == no CAN, no Crypto, YES RNG, F/H == 2x CAN, no Crypto, YES RNG, K/M == 2xCAN, YES Crypto, YES RNG
143 | PIC32MZ EF | PIC32MZ0512EFF064 | 64 | TQFP,QFN | 160 | 512 | 128 | YES (needs procdefs) | NO |  | // 2048 H available in 252MHz variant
144 | PIC32MZ EF | PIC32MZ0512EFK064 | 64 | TQFP,QFN | 160 | 512 | 128 | YES (needs procdefs) | NO
145 | PIC32MZ EF | PIC32MZ1024EFE064 | 64 | TQFP,QFN | 160 | 1024 | 256 | YES (needs procdefs) | NO
146 | PIC32MZ EF | PIC32MZ1024EFF064 | 64 | TQFP,QFN | 160 | 1024 | 256 | YES (needs procdefs) | NO
147 | PIC32MZ EF | PIC32MZ1024EFK064 | 64 | TQFP,QFN | 160 | 1024 | 256 | YES (needs procdefs) | NO
148 | PIC32MZ EF | PIC32MZ0512EFE100 | 100 | TQFP,TFBGA | 160 | 512 | 128 | YES (needs procdefs) | NO
149 | PIC32MZ EF | PIC32MZ0512EFF100 | 100 | TQFP,TFBGA | 160 | 512 | 128 | YES (needs procdefs) | NO
150 | PIC32MZ EF | PIC32MZ0512EFK100 | 100 | TQFP,TFBGA | 160 | 512 | 128 | YES (needs procdefs) | NO
151 | PIC32MZ EF | PIC32MZ1024EFE100 | 100 | TQFP,TFBGA | 160 | 1024 | 256 | YES (needs procdefs) | NO
152 | PIC32MZ EF | PIC32MZ1024EFF100 | 100 | TQFP,TFBGA | 160 | 1024 | 256 | YES (needs procdefs) | NO
153 | PIC32MZ EF | PIC32MZ1024EFK100 | 100 | TQFP,TFBGA | 160 | 1024 | 256 | YES (needs procdefs) | NO
154 | PIC32MZ EF | PIC32MZ0512EFE124 | 124 | VTLA | 160 | 512 | 128 | YES (needs procdefs) | NO
155 | PIC32MZ EF | PIC32MZ0512EFF124 | 124 | VTLA | 160 | 512 | 128 | YES (needs procdefs) | NO
156 | PIC32MZ EF | PIC32MZ0512EFK124 | 124 | VTLA | 160 | 512 | 128 | YES (needs procdefs) | NO
157 | PIC32MZ EF | PIC32MZ1024EFE124 | 124 | VTLA | 160 | 1024 | 256 | YES (needs procdefs) | NO
158 | PIC32MZ EF | PIC32MZ1024EFF124 | 124 | VTLA | 160 | 1024 | 256 | YES (needs procdefs) | NO
159 | PIC32MZ EF | PIC32MZ1024EFK124 | 124 | VTLA | 160 | 1024 | 256 | YES (needs procdefs) | NO
160 | PIC32MZ EF | PIC32MZ0512EFE144 | 144 | LQFP,TQFP,TFBGA | 160 | 512 | 128 | YES (needs procdefs) | NO
161 | PIC32MZ EF | PIC32MZ0512EFF144 | 144 | LQFP,TQFP,TFBGA | 160 | 512 | 128 | YES (needs procdefs) | NO
162 | PIC32MZ EF | PIC32MZ0512EFK144 | 144 | LQFP,TQFP,TFBGA | 160 | 512 | 128 | YES (needs procdefs) | NO
163 | PIC32MZ EF | PIC32MZ1024EFE144 | 144 | LQFP,TQFP,TFBGA | 160 | 1024 | 256 | YES (needs procdefs) | NO
164 | PIC32MZ EF | PIC32MZ1024EFF144 | 144 | LQFP,TQFP,TFBGA | 160 | 1024 | 256 | YES (needs procdefs) | NO
165 | PIC32MZ EF | PIC32MZ1024EFK144 | 144 | LQFP,TQFP,TFBGA | 160 | 1024 | 256 | YES (needs procdefs) | NO
166 | PIC32MZ EF | PIC32MZ1024EFG064 | 64 | TQFP,QFN | 160 | 1024 | 512 | YES (needs procdefs) | NO
167 | PIC32MZ EF | PIC32MZ1024EFH064 | 64 | TQFP,QFN | 160 | 1024 | 512 | YES (needs procdefs) | NO
168 | PIC32MZ EF | PIC32MZ1024EFM064 | 64 | TQFP,QFN | 160 | 1024 | 512 | YES (needs procdefs) | NO
169 | PIC32MZ EF | PIC32MZ2048EFG064 | 64 | TQFP,QFN | 160 | 2048 | 512 | YES (needs procdefs) | NO
170 | PIC32MZ EF | PIC32MZ2048EFH064 | 64 | TQFP,QFN | 160 | 2048 | 512 | YES (needs procdefs) | NO
171 | PIC32MZ EF | PIC32MZ2048EFM064 | 64 | TQFP,QFN | 160 | 2048 | 512 | YES (needs procdefs) | NO | Ordered
172 | PIC32MZ EF | PIC32MZ1024EFG100 | 100 | TQFP,TFBGA | 160 | 1024 | 512 | YES (needs procdefs) | NO
173 | PIC32MZ EF | PIC32MZ1024EFH100 | 100 | TQFP,TFBGA | 160 | 1024 | 512 | YES (needs procdefs) | NO
174 | PIC32MZ EF | PIC32MZ1024EFM100 | 100 | TQFP,TFBGA | 160 | 1024 | 512 | YES (needs procdefs) | NO
175 | PIC32MZ EF | PIC32MZ2048EFG100 | 100 | TQFP,TFBGA | 160 | 2048 | 512 | YES (needs procdefs) | NO
176 | PIC32MZ EF | PIC32MZ2048EFH100 | 100 | TQFP,TFBGA | 160 | 2048 | 512 | YES (needs procdefs) | NO
177 | PIC32MZ EF | PIC32MZ2048EFM100 | 100 | TQFP,TFBGA | 160 | 2048 | 512 | YES (needs procdefs) | NO
178 | PIC32MZ EF | PIC32MZ1024EFG124 | 124 | VTLA | 160 | 1024 | 512 | YES (needs procdefs) | NO
179 | PIC32MZ EF | PIC32MZ1024EFH124 | 124 | VTLA | 160 | 1024 | 512 | YES (needs procdefs) | NO
180 | PIC32MZ EF | PIC32MZ1024EFM124 | 124 | VTLA | 160 | 1024 | 512 | YES (needs procdefs) | NO
181 | PIC32MZ EF | PIC32MZ2048EFG124 | 124 | VTLA | 160 | 2048 | 512 | YES (needs procdefs) | NO
182 | PIC32MZ EF | PIC32MZ2048EFH124 | 124 | VTLA | 160 | 2048 | 512 | YES (needs procdefs) | NO
183 | PIC32MZ EF | PIC32MZ2048EFM124 | 124 | VTLA | 160 | 2048 | 512 | YES (needs procdefs) | NO
184 | PIC32MZ EF | PIC32MZ1024EFG144 | 144 | LQFP,TQFP,TFBGA | 160 | 1024 | 512 | YES (needs procdefs) | NO
185 | PIC32MZ EF | PIC32MZ1024EFH144 | 144 | LQFP,TQFP,TFBGA | 160 | 1024 | 512 | YES (needs procdefs) | NO
186 | PIC32MZ EF | PIC32MZ1024EFM144 | 144 | LQFP,TQFP,TFBGA | 160 | 1024 | 512 | YES (needs procdefs) | NO
187 | PIC32MZ EF | PIC32MZ2048EFG144 | 144 | LQFP,TQFP,TFBGA | 160 | 2048 | 512 | YES (needs procdefs) | NO
188 | PIC32MZ EF | PIC32MZ2048EFH144 | 144 | LQFP,TQFP,TFBGA | 160 | 2048 | 512 | YES (needs procdefs) | NO
189 | PIC32MZ EF | PIC32MZ2048EFM144 | 144 | LQFP,TQFP,TFBGA | 160 | 2048 | 512 | YES | NO | YES (board)
190 | PIC32MZ DA (A/B/G/H) | PIC32MZ1025DAA169 | 169 | LFBGA (HF) | 160 | 1024 | 256 | PROBABLY (needs procdefs) | NO |  | // A/B/G/H are superseded by K/L/R/S
191 | PIC32MZ DA (A/B/G/H) | PIC32MZ1025DAB169 | 169 | LFBGA (HF) | 160 | 1024 | 256 | PROBABLY (needs procdefs) | NO |  | // G/H have internal DDR2 interface and 32MB RAM
192 | PIC32MZ DA (A/B/G/H) | PIC32MZ1064DAA169 | 169 | LFBGA (HF) | 160 | 1024 | 640 | PROBABLY (needs procdefs) | NO |  | // A/B in 4J package have an external DDR2 interface
193 | PIC32MZ DA (A/B/G/H) | PIC32MZ1064DAB169 | 169 | LFBGA (HF) | 160 | 1024 | 640 | PROBABLY (needs procdefs) | NO |  | // Boot flash is 2x 80kB (dual panel)
194 | PIC32MZ DA (A/B/G/H) | PIC32MZ2025DAA169 | 169 | LFBGA (HF) | 160 | 2048 | 256 | PROBABLY (needs procdefs) | NO |  | // DA has same vectors etc. as EF
195 | PIC32MZ DA (A/B/G/H) | PIC32MZ2025DAB169 | 169 | LFBGA (HF) | 160 | 2048 | 256 | PROBABLY (needs procdefs) | NO
196 | PIC32MZ DA (A/B/G/H) | PIC32MZ2064DAA169 | 169 | LFBGA (HF) | 160 | 2048 | 640 | PROBABLY (needs procdefs) | NO
197 | PIC32MZ DA (A/B/G/H) | PIC32MZ2064DAB169 | 169 | LFBGA (HF) | 160 | 2048 | 640 | PROBABLY (needs procdefs) | NO
198 | PIC32MZ DA (A/B/G/H) | PIC32MZ1025DAG169 | 169 | LFBGA (6JX) | 160 | 1024 | 256 | PROBABLY (needs procdefs) | NO
199 | PIC32MZ DA (A/B/G/H) | PIC32MZ1025DAH169 | 169 | LFBGA (6JX) | 160 | 1024 | 256 | PROBABLY (needs procdefs) | NO
200 | PIC32MZ DA (A/B/G/H) | PIC32MZ1064DAG169 | 169 | LFBGA (6JX) | 160 | 1024 | 640 | PROBABLY (needs procdefs) | NO
201 | PIC32MZ DA (A/B/G/H) | PIC32MZ1064DAH169 | 169 | LFBGA (6JX) | 160 | 1024 | 640 | PROBABLY (needs procdefs) | NO
202 | PIC32MZ DA (A/B/G/H) | PIC32MZ2025DAG169 | 169 | LFBGA (6JX) | 160 | 2048 | 256 | PROBABLY (needs procdefs) | NO
203 | PIC32MZ DA (A/B/G/H) | PIC32MZ2025DAH169 | 169 | LFBGA (6JX) | 160 | 2048 | 256 | PROBABLY (needs procdefs) | NO
204 | PIC32MZ DA (A/B/G/H) | PIC32MZ2064DAG169 | 169 | LFBGA (6JX) | 160 | 2048 | 640 | PROBABLY (needs procdefs) | NO
205 | PIC32MZ DA (A/B/G/H) | PIC32MZ2064DAH169 | 169 | LFBGA (6JX) | 160 | 2048 | 640 | PROBABLY (needs procdefs) | NO
206 | PIC32MZ DA (A/B/G/H) | PIC32MZ1025DAA176 | 176 | LQFP | 160 | 1024 | 256 | PROBABLY (needs procdefs) | NO
207 | PIC32MZ DA (A/B/G/H) | PIC32MZ1025DAB176 | 176 | LQFP | 160 | 1024 | 256 | PROBABLY (needs procdefs) | NO
208 | PIC32MZ DA (A/B/G/H) | PIC32MZ1064DAA176 | 176 | LQFP | 160 | 1024 | 640 | PROBABLY (needs procdefs) | NO
209 | PIC32MZ DA (A/B/G/H) | PIC32MZ1064DAB176 | 176 | LQFP | 160 | 1024 | 640 | PROBABLY (needs procdefs) | NO
210 | PIC32MZ DA (A/B/G/H) | PIC32MZ2025DAA176 | 176 | LQFP | 160 | 2048 | 256 | PROBABLY (needs procdefs) | NO
211 | PIC32MZ DA (A/B/G/H) | PIC32MZ2025DAB176 | 176 | LQFP | 160 | 2048 | 256 | PROBABLY (needs procdefs) | NO
212 | PIC32MZ DA (A/B/G/H) | PIC32MZ2064DAA176 | 176 | LQFP | 160 | 2048 | 640 | PROBABLY (needs procdefs) | NO
213 | PIC32MZ DA (A/B/G/H) | PIC32MZ2064DAB176 | 176 | LQFP | 160 | 2048 | 640 | PROBABLY (needs procdefs) | NO | Ordered
214 | PIC32MZ DA (A/B/G/H) | PIC32MZ1025DAG176 | 176 | LQFP | 160 | 1024 | 256 | PROBABLY (needs procdefs) | NO
215 | PIC32MZ DA (A/B/G/H) | PIC32MZ1025DAH176 | 176 | LQFP | 160 | 1024 | 256 | PROBABLY (needs procdefs) | NO
216 | PIC32MZ DA (A/B/G/H) | PIC32MZ1064DAG176 | 176 | LQFP | 160 | 1024 | 640 | PROBABLY (needs procdefs) | NO
217 | PIC32MZ DA (A/B/G/H) | PIC32MZ1064DAH176 | 176 | LQFP | 160 | 1024 | 640 | PROBABLY (needs procdefs) | NO
218 | PIC32MZ DA (A/B/G/H) | PIC32MZ2025DAG176 | 176 | LQFP | 160 | 2048 | 256 | PROBABLY (needs procdefs) | NO
219 | PIC32MZ DA (A/B/G/H) | PIC32MZ2025DAH176 | 176 | LQFP | 160 | 2048 | 256 | PROBABLY (needs procdefs) | NO | Ordered
220 | PIC32MZ DA (A/B/G/H) | PIC32MZ2064DAG176 | 176 | LQFP | 160 | 2048 | 640 | PROBABLY (needs procdefs) | NO
221 | PIC32MZ DA (A/B/G/H) | PIC32MZ2064DAH176 | 176 | LQFP | 160 | 2048 | 640 | PROBABLY (needs procdefs) | NO
222 | PIC32MZ DA (A/B/G/H) | PIC32MZ1025DAA288 | 288 | LFBGA (4J) | 160 | 1024 | 256 | PROBABLY (needs procdefs) | NO
223 | PIC32MZ DA (A/B/G/H) | PIC32MZ1025DAB288 | 288 | LFBGA (4J) | 160 | 1024 | 256 | PROBABLY (needs procdefs) | NO
224 | PIC32MZ DA (A/B/G/H) | PIC32MZ1064DAA288 | 288 | LFBGA (4J) | 160 | 1024 | 640 | PROBABLY (needs procdefs) | NO
225 | PIC32MZ DA (A/B/G/H) | PIC32MZ1064DAB288 | 288 | LFBGA (4J) | 160 | 1024 | 640 | PROBABLY (needs procdefs) | NO
226 | PIC32MZ DA (A/B/G/H) | PIC32MZ2025DAA288 | 288 | LFBGA (4J) | 160 | 2048 | 256 | PROBABLY (needs procdefs) | NO
227 | PIC32MZ DA (A/B/G/H) | PIC32MZ2025DAB288 | 288 | LFBGA (4J) | 160 | 2048 | 256 | PROBABLY (needs procdefs) | NO
228 | PIC32MZ DA (A/B/G/H) | PIC32MZ2064DAA288 | 288 | LFBGA (4J) | 160 | 2048 | 640 | PROBABLY (needs procdefs) | NO
229 | PIC32MZ DA (A/B/G/H) | PIC32MZ2064DAB288 | 288 | LFBGA (4J) | 160 | 2048 | 640 | PROBABLY (needs procdefs) | NO
230 | PIC32MZ DA (K/L/R/S) | PIC32MZ1025DAK169 | 169 | LFBGA (HF) | 160 | 1024 | 256 | PROBABLY (needs procdefs) | NO |  | // R/S has integrated DDR2 internal interface, with 32MB RAM
231 | PIC32MZ DA (K/L/R/S) | PIC32MZ1025DAL169 | 169 | LFBGA (HF) | 160 | 1024 | 256 | PROBABLY (needs procdefs) | NO |  | // Boot flash is 2x 80kB (dual panel)
232 | PIC32MZ DA (K/L/R/S) | PIC32MZ1064DAK169 | 169 | LFBGA (HF) | 160 | 1024 | 640 | PROBABLY (needs procdefs) | NO
233 | PIC32MZ DA (K/L/R/S) | PIC32MZ1064DAL169 | 169 | LFBGA (HF) | 160 | 1024 | 640 | PROBABLY (needs procdefs) | NO
234 | PIC32MZ DA (K/L/R/S) | PIC32MZ2025DAK169 | 169 | LFBGA (HF) | 160 | 2048 | 256 | PROBABLY (needs procdefs) | NO
235 | PIC32MZ DA (K/L/R/S) | PIC32MZ2025DAL169 | 169 | LFBGA (HF) | 160 | 2048 | 256 | PROBABLY (needs procdefs) | NO
236 | PIC32MZ DA (K/L/R/S) | PIC32MZ2064DAK169 | 169 | LFBGA (HF) | 160 | 2048 | 640 | PROBABLY (needs procdefs) | NO
237 | PIC32MZ DA (K/L/R/S) | PIC32MZ2064DAL169 | 169 | LFBGA (HF) | 160 | 2048 | 640 | PROBABLY (needs procdefs) | NO
238 | PIC32MZ DA (K/L/R/S) | PIC32MZ1025DAR169 | 169 | LFBGA (6JX) | 160 | 1024 | 256 | PROBABLY (needs procdefs) | NO
239 | PIC32MZ DA (K/L/R/S) | PIC32MZ1025DAS169 | 169 | LFBGA (6JX) | 160 | 1024 | 256 | PROBABLY (needs procdefs) | NO
240 | PIC32MZ DA (K/L/R/S) | PIC32MZ1064DAR169 | 169 | LFBGA (6JX) | 160 | 1024 | 640 | PROBABLY (needs procdefs) | NO
241 | PIC32MZ DA (K/L/R/S) | PIC32MZ1064DAS169 | 169 | LFBGA (6JX) | 160 | 1024 | 640 | PROBABLY (needs procdefs) | NO
242 | PIC32MZ DA (K/L/R/S) | PIC32MZ2025DAR169 | 169 | LFBGA (6JX) | 160 | 2048 | 256 | PROBABLY (needs procdefs) | NO
243 | PIC32MZ DA (K/L/R/S) | PIC32MZ2025DAS169 | 169 | LFBGA (6JX) | 160 | 2048 | 256 | PROBABLY (needs procdefs) | NO
244 | PIC32MZ DA (K/L/R/S) | PIC32MZ2064DAR169 | 169 | LFBGA (6JX) | 160 | 2048 | 640 | PROBABLY (needs procdefs) | NO
245 | PIC32MZ DA (K/L/R/S) | PIC32MZ2064DAS169 | 169 | LFBGA (6JX) | 160 | 2048 | 640 | PROBABLY (needs procdefs) | NO
246 | PIC32MZ DA (K/L/R/S) | PIC32MZ1025DAK176 | 176 | LQFP | 160 | 1024 | 256 | PROBABLY (needs procdefs) | NO
247 | PIC32MZ DA (K/L/R/S) | PIC32MZ1025DAL176 | 176 | LQFP | 160 | 1024 | 256 | PROBABLY (needs procdefs) | NO
248 | PIC32MZ DA (K/L/R/S) | PIC32MZ1064DAK176 | 176 | LQFP | 160 | 1024 | 640 | PROBABLY (needs procdefs) | NO
249 | PIC32MZ DA (K/L/R/S) | PIC32MZ1064DAL176 | 176 | LQFP | 160 | 1024 | 640 | PROBABLY (needs procdefs) | NO
250 | PIC32MZ DA (K/L/R/S) | PIC32MZ2025DAK176 | 176 | LQFP | 160 | 2048 | 256 | PROBABLY (needs procdefs) | NO
251 | PIC32MZ DA (K/L/R/S) | PIC32MZ2025DAL176 | 176 | LQFP | 160 | 2048 | 256 | PROBABLY (needs procdefs) | NO
252 | PIC32MZ DA (K/L/R/S) | PIC32MZ2064DAK176 | 176 | LQFP | 160 | 2048 | 640 | PROBABLY (needs procdefs) | NO
253 | PIC32MZ DA (K/L/R/S) | PIC32MZ2064DAL176 | 176 | LQFP | 160 | 2048 | 640 | PROBABLY (needs procdefs) | NO | Ordered
254 | PIC32MZ DA (K/L/R/S) | PIC32MZ1025DAR176 | 176 | LQFP | 160 | 1024 | 256 | PROBABLY (needs procdefs) | NO
255 | PIC32MZ DA (K/L/R/S) | PIC32MZ1025DAS176 | 176 | LQFP | 160 | 1024 | 256 | PROBABLY (needs procdefs) | NO
256 | PIC32MZ DA (K/L/R/S) | PIC32MZ1064DAR176 | 176 | LQFP | 160 | 1024 | 640 | PROBABLY (needs procdefs) | NO
257 | PIC32MZ DA (K/L/R/S) | PIC32MZ1064DAS176 | 176 | LQFP | 160 | 1024 | 640 | PROBABLY (needs procdefs) | NO
258 | PIC32MZ DA (K/L/R/S) | PIC32MZ2025DAR176 | 176 | LQFP | 160 | 2048 | 256 | PROBABLY (needs procdefs) | NO
259 | PIC32MZ DA (K/L/R/S) | PIC32MZ2025DAS176 | 176 | LQFP | 160 | 2048 | 256 | PROBABLY (needs procdefs) | NO | Ordered
260 | PIC32MZ DA (K/L/R/S) | PIC32MZ2064DAR176 | 176 | LQFP | 160 | 2048 | 640 | PROBABLY (needs procdefs) | NO
261 | PIC32MZ DA (K/L/R/S) | PIC32MZ2064DAS176 | 176 | LQFP | 160 | 2048 | 640 | PROBABLY (needs procdefs) | NO
262 | PIC32MZ EC | PIC32MZ1024ECG064 | 64 | TQFP,QFN | 160 | 1024 | 512 | NO (needs new lookup table) | NO |  | // Doesn’t exist anymore – superseded by EF
263 | PIC32MZ EC | PIC32MZ1024ECH064 | 64 | TQFP,QFN | 160 | 1024 | 512 | NO (needs new lookup table) | NO |  | // G == no CAN, no Crypto, YES RNG, H == 2x CAN, no Crypto, YES RNG, M == 2x CAN, YES Crypto, Yes RNG
264 | PIC32MZ EC | PIC32MZ1024ECM064 | 64 | TQFP,QFN | 160 | 1024 | 512 | NO (needs new lookup table) | NO
265 | PIC32MZ EC | PIC32MZ2048ECG064 | 64 | TQFP,QFN | 160 | 2048 | 512 | NO (needs new lookup table) | NO
266 | PIC32MZ EC | PIC32MZ2048ECH064 | 64 | TQFP,QFN | 160 | 2048 | 512 | NO (needs new lookup table) | NO
267 | PIC32MZ EC | PIC32MZ2048ECM064 | 64 | TQFP,QFN | 160 | 2048 | 512 | NO (needs new lookup table) | NO
268 | PIC32MZ EC | PIC32MZ1024ECG100 | 100 | TQFP | 160 | 1024 | 512 | NO (needs new lookup table) | NO
269 | PIC32MZ EC | PIC32MZ1024ECH100 | 100 | TQFP | 160 | 1024 | 512 | NO (needs new lookup table) | NO
270 | PIC32MZ EC | PIC32MZ1024ECM100 | 100 | TQFP | 160 | 1024 | 512 | NO (needs new lookup table) | NO
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

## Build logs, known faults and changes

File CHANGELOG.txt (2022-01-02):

Rev1 notes:
- Backplane, MASTER_CLR should have a pull-up
- RiserCard, Power LED should be powered from VCC/VDD, nor +3v3. Other from +3v3.

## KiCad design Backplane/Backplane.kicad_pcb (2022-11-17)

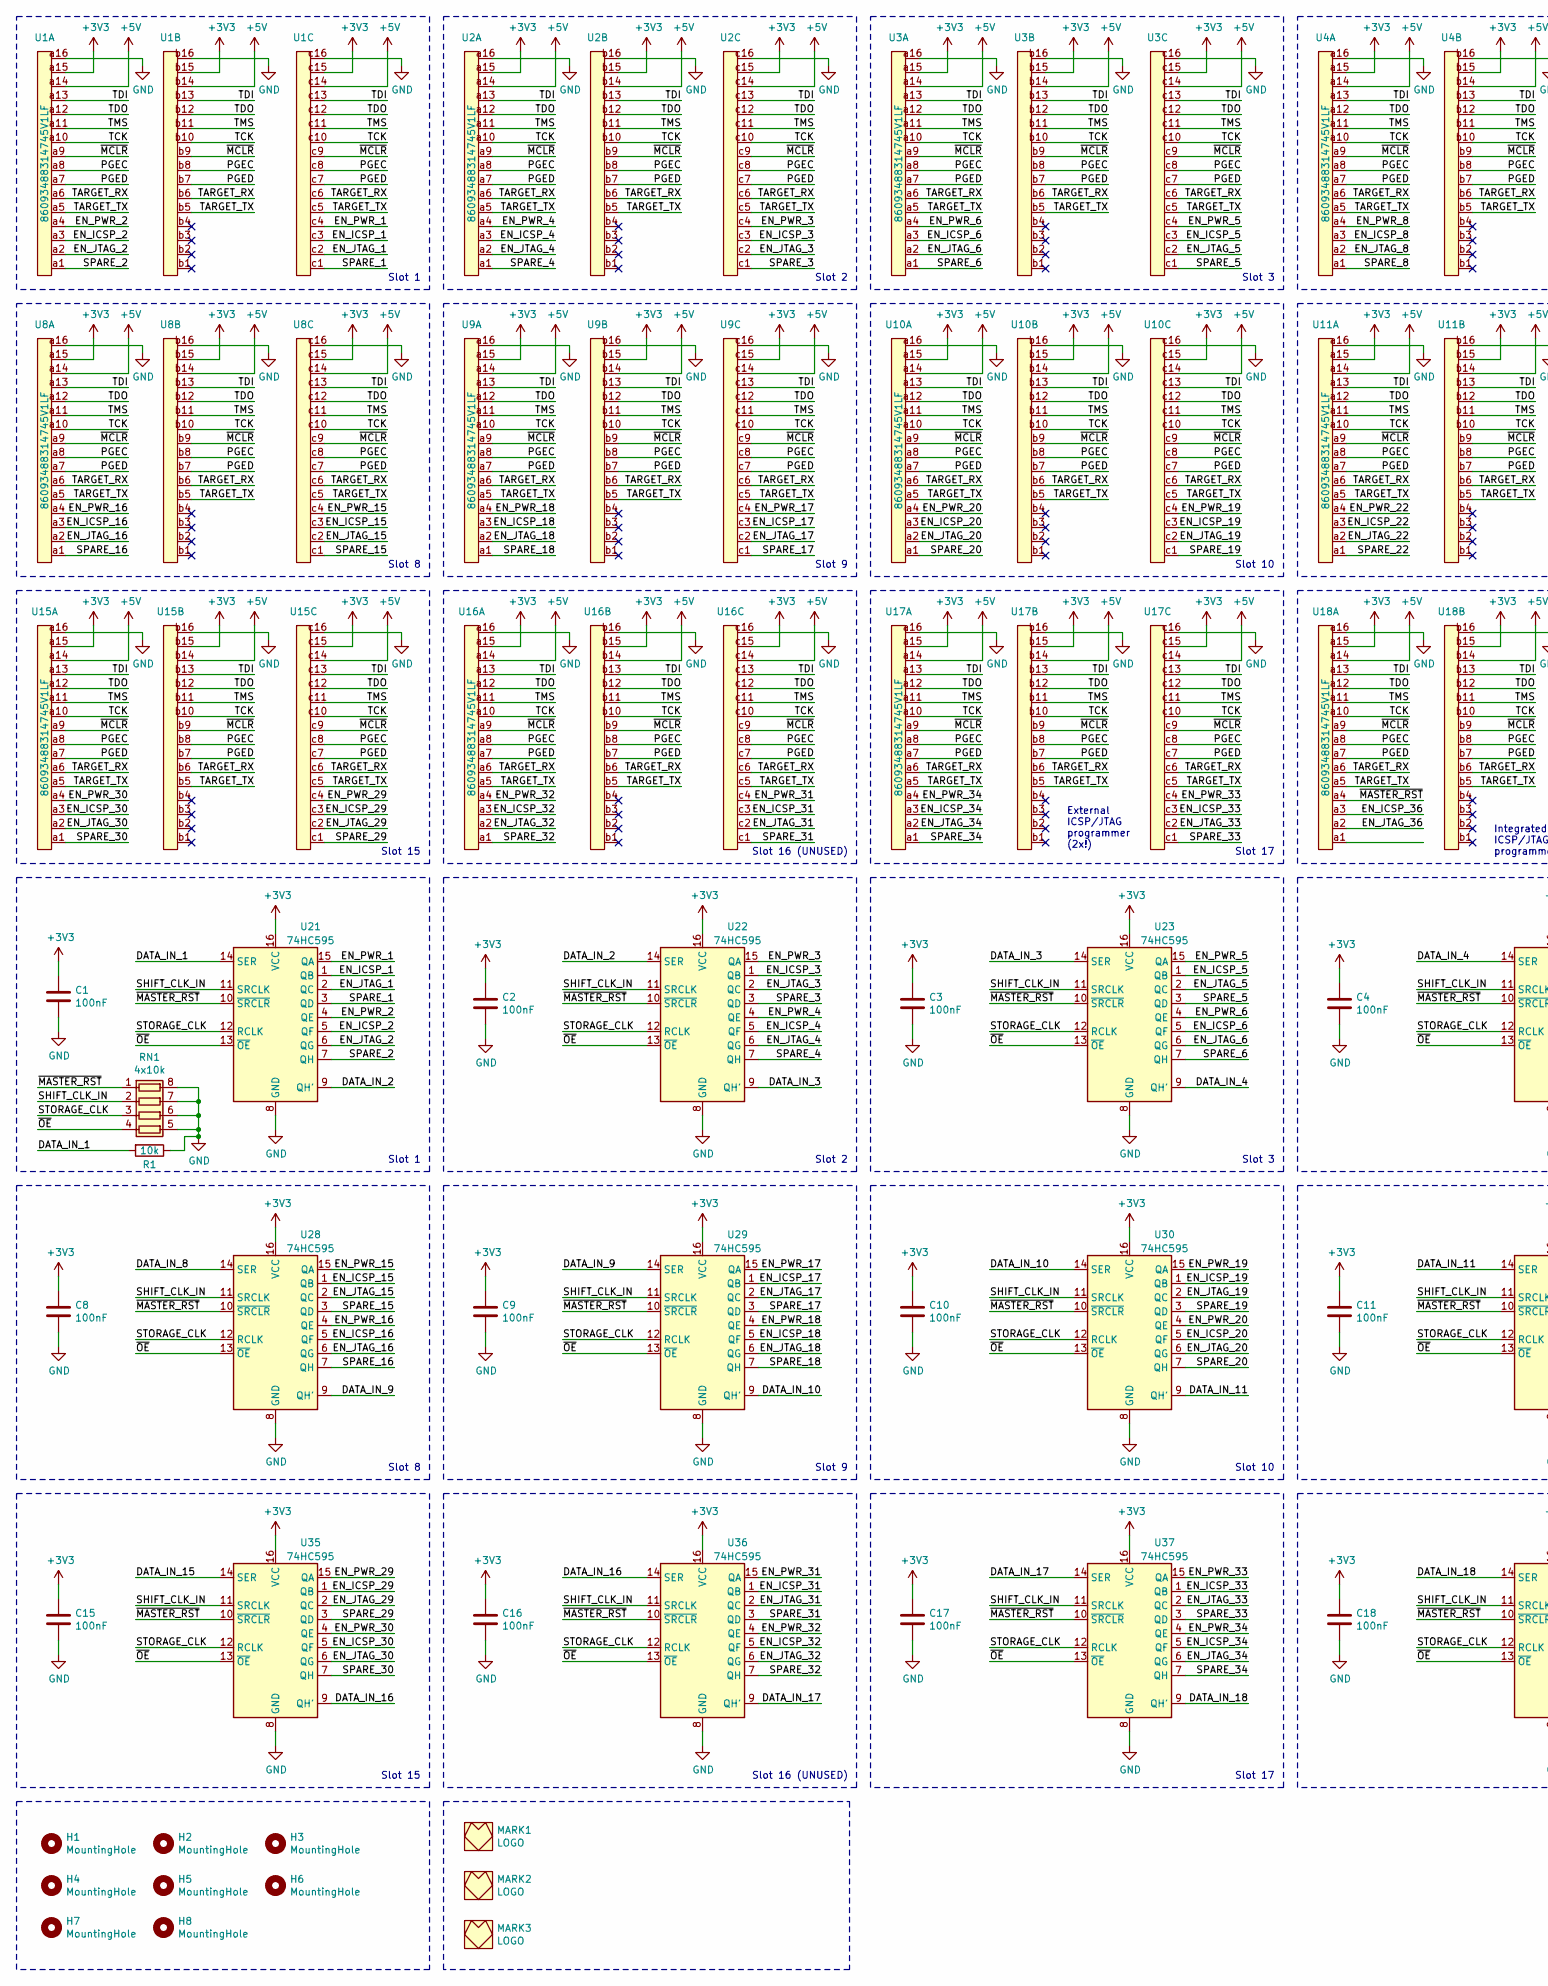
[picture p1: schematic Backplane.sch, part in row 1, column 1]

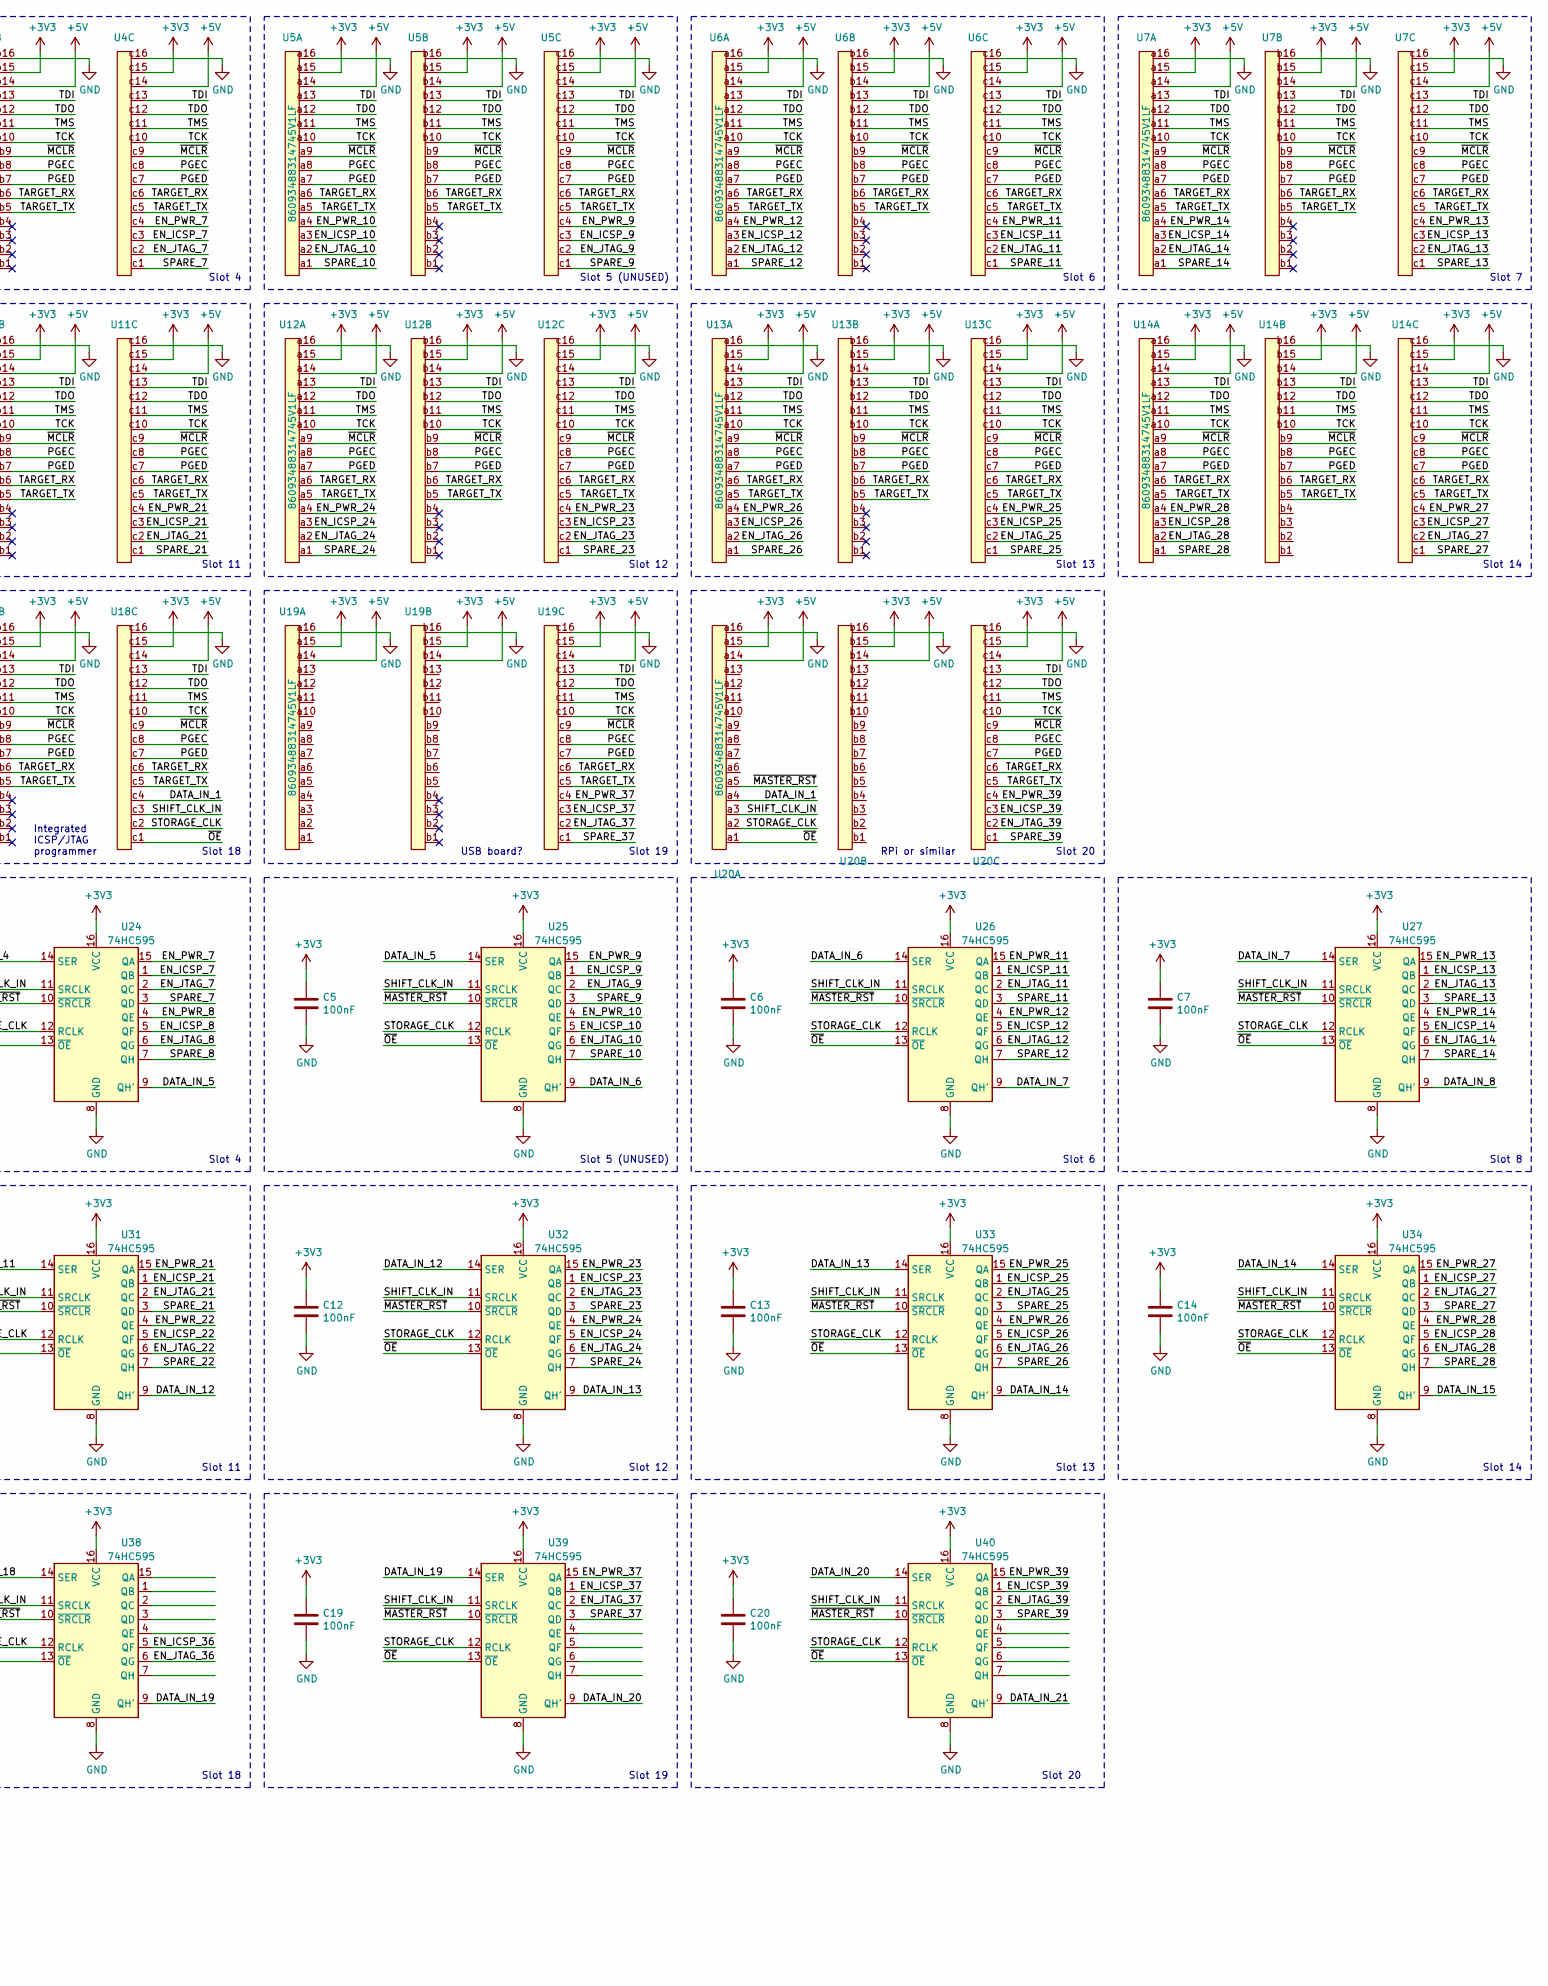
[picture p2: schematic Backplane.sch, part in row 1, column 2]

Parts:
C1, C2, C3, C4, C5, C6, C7, C8, C9, C10, C11, C12, C13, C14, C15, C16, C17, C18, C19, C20: 100nF; C_0603_1608Metric_Pad1.08x0.95mm_HandSolder
H1, H2, H3, H4, H5, H6, H7, H8: MountingHole; MountingHole_3.2mm_M3
MARK1: LOGO; FOX_LOGO_COPPER
MARK2: LOGO; FOX_LOGO_MASK
MARK3: LOGO; FOX_LOGO_SILK
R1: 10k; R_0603_1608Metric_Pad0.98x0.95mm_HandSolder
RN1: 4x10k; R_Array_Convex_4x0603
U1, U2, U3, U4, U5, U6, U7, U8, U9, U10, U11, U12, U13, U14, U15, U16, U17, U18, U19, U20: 86093488314745V1LF; DIN41612_C2_3x16_Female_Vertical_THT; Mouser 649-869348314745V1LF
U21, U22, U23, U24, U25, U26, U27, U28, U29, U30, U31, U32, U33, U34, U35, U36, U37, U38, U39, U40: 74HC595; TSSOP-16_4.4x5mm_P0.65mm

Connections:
+3V3: C1.1, C2.1, C3.1, C4.1, C5.1, C6.1, C7.1, C8.1, C9.1, C10.1, C11.1, C12.1, C13.1, C14.1, C15.1, C16.1, C17.1, C18.1, C19.1, C20.1, U1.a15, U1.b15, U1.c15, U2.a15, U2.b15, U2.c15, U3.a15, U3.b15, U3.c15, U4.a15, U4.b15, U4.c15, U5.a15, U5.b15, U5.c15, U6.a15, U6.b15, U6.c15, U7.a15, U7.b15, U7.c15, U8.a15, U8.b15, U8.c15, U9.a15, U9.b15, U9.c15, U10.a15, U10.b15, U10.c15, U11.a15, U11.b15, U11.c15, U12.a15, U12.b15, U12.c15, U13.a15, U13.b15, U13.c15, U14.a15, U14.b15, U14.c15, U15.a15, U15.b15, U15.c15, U16.a15, U16.b15, U16.c15, U17.a15, U17.b15, U17.c15, U18.a15, U18.b15, U18.c15, U19.a15, U19.b15, U19.c15, U20.a15, U20.b15, U20.c15, U21.16 (VCC), U22.16 (VCC), U23.16 (VCC), U24.16 (VCC), U25.16 (VCC), U26.16 (VCC), U27.16 (VCC), U28.16 (VCC), U29.16 (VCC), U30.16 (VCC), U31.16 (VCC), U32.16 (VCC), U33.16 (VCC), U34.16 (VCC), U35.16 (VCC), U36.16 (VCC), U37.16 (VCC), U38.16 (VCC), U39.16 (VCC), U40.16 (VCC)
+5V: U1.a14, U1.b14, U1.c14, U2.a14, U2.b14, U2.c14, U3.a14, U3.b14, U3.c14, U4.a14, U4.b14, U4.c14, U5.a14, U5.b14, U5.c14, U6.a14, U6.b14, U6.c14, U7.a14, U7.b14, U7.c14, U8.a14, U8.b14, U8.c14, U9.a14, U9.b14, U9.c14, U10.a14, U10.b14, U10.c14, U11.a14, U11.b14, U11.c14, U12.a14, U12.b14, U12.c14, U13.a14, U13.b14, U13.c14, U14.a14, U14.b14, U14.c14, U15.a14, U15.b14, U15.c14, U16.a14, U16.b14, U16.c14, U17.a14, U17.b14, U17.c14, U18.a14, U18.b14, U18.c14, U19.a14, U19.b14, U19.c14, U20.a14, U20.b14, U20.c14
/DATA_IN_1: R1.2, U18.c4, U20.a4, U21.14 (SER)
/DATA_IN_2: U21.9 (QH'), U22.14 (SER)
/DATA_IN_3: U22.9 (QH'), U23.14 (SER)
/DATA_IN_4: U23.9 (QH'), U24.14 (SER)
/DATA_IN_5: U24.9 (QH'), U25.14 (SER)
/DATA_IN_6: U25.9 (QH'), U26.14 (SER)
/DATA_IN_7: U26.9 (QH'), U27.14 (SER)
/DATA_IN_8: U27.9 (QH'), U28.14 (SER)
/DATA_IN_9: U28.9 (QH'), U29.14 (SER)
/DATA_IN_10: U29.9 (QH'), U30.14 (SER)
/DATA_IN_11: U30.9 (QH'), U31.14 (SER)
/DATA_IN_12: U31.9 (QH'), U32.14 (SER)
/DATA_IN_13: U32.9 (QH'), U33.14 (SER)
/DATA_IN_14: U33.9 (QH'), U34.14 (SER)
/DATA_IN_15: U34.9 (QH'), U35.14 (SER)
/DATA_IN_16: U35.9 (QH'), U36.14 (SER)
/DATA_IN_17: U36.9 (QH'), U37.14 (SER)
/DATA_IN_18: U37.9 (QH'), U38.14 (SER)
/DATA_IN_19: U38.9 (QH'), U39.14 (SER)
/DATA_IN_20: U39.9 (QH'), U40.14 (SER)
/EN_ICSP_1: U1.c3, U21.1 (QB)
/EN_ICSP_2: U1.a3, U21.5 (QF)
/EN_ICSP_3: U2.c3, U22.1 (QB)
/EN_ICSP_4: U2.a3, U22.5 (QF)
/EN_ICSP_5: U3.c3, U23.1 (QB)
/EN_ICSP_6: U3.a3, U23.5 (QF)
/EN_ICSP_7: U4.c3, U24.1 (QB)
/EN_ICSP_8: U4.a3, U24.5 (QF)
/EN_ICSP_9: U5.c3, U25.1 (QB)
/EN_ICSP_10: U5.a3, U25.5 (QF)
/EN_ICSP_11: U6.c3, U26.1 (QB)
/EN_ICSP_12: U6.a3, U26.5 (QF)
/EN_ICSP_13: U7.c3, U27.1 (QB)
/EN_ICSP_14: U7.a3, U27.5 (QF)
/EN_ICSP_15: U8.c3, U28.1 (QB)
/EN_ICSP_16: U8.a3, U28.5 (QF)
/EN_ICSP_17: U9.c3, U29.1 (QB)
/EN_ICSP_18: U9.a3, U29.5 (QF)
/EN_ICSP_19: U10.c3, U30.1 (QB)
/EN_ICSP_20: U10.a3, U30.5 (QF)
/EN_ICSP_21: U11.c3, U31.1 (QB)
/EN_ICSP_22: U11.a3, U31.5 (QF)
/EN_ICSP_23: U12.c3, U32.1 (QB)
/EN_ICSP_24: U12.a3, U32.5 (QF)
/EN_ICSP_25: U13.c3, U33.1 (QB)
/EN_ICSP_26: U13.a3, U33.5 (QF)
/EN_ICSP_27: U14.c3, U34.1 (QB)
/EN_ICSP_28: U14.a3, U34.5 (QF)
/EN_ICSP_29: U15.c3, U35.1 (QB)
/EN_ICSP_30: U15.a3, U35.5 (QF)
/EN_ICSP_31: U16.c3, U36.1 (QB)
/EN_ICSP_32: U16.a3, U36.5 (QF)
/EN_ICSP_33: U17.c3, U37.1 (QB)
/EN_ICSP_34: U17.a3, U37.5 (QF)
/EN_ICSP_36: U18.a3, U38.5 (QF)
/EN_ICSP_37: U19.c3, U39.1 (QB)
/EN_ICSP_39: U20.c3, U40.1 (QB)
/EN_JTAG_1: U1.c2, U21.2 (QC)
/EN_JTAG_2: U1.a2, U21.6 (QG)
/EN_JTAG_3: U2.c2, U22.2 (QC)
/EN_JTAG_4: U2.a2, U22.6 (QG)
/EN_JTAG_5: U3.c2, U23.2 (QC)
/EN_JTAG_6: U3.a2, U23.6 (QG)
/EN_JTAG_7: U4.c2, U24.2 (QC)
/EN_JTAG_8: U4.a2, U24.6 (QG)
/EN_JTAG_9: U5.c2, U25.2 (QC)
/EN_JTAG_10: U5.a2, U25.6 (QG)
/EN_JTAG_11: U6.c2, U26.2 (QC)
/EN_JTAG_12: U6.a2, U26.6 (QG)
/EN_JTAG_13: U7.c2, U27.2 (QC)
/EN_JTAG_14: U7.a2, U27.6 (QG)
/EN_JTAG_15: U8.c2, U28.2 (QC)
/EN_JTAG_16: U8.a2, U28.6 (QG)
/EN_JTAG_17: U9.c2, U29.2 (QC)
/EN_JTAG_18: U9.a2, U29.6 (QG)
/EN_JTAG_19: U10.c2, U30.2 (QC)
/EN_JTAG_20: U10.a2, U30.6 (QG)
/EN_JTAG_21: U11.c2, U31.2 (QC)
/EN_JTAG_22: U11.a2, U31.6 (QG)
/EN_JTAG_23: U12.c2, U32.2 (QC)
/EN_JTAG_24: U12.a2, U32.6 (QG)
/EN_JTAG_25: U13.c2, U33.2 (QC)
/EN_JTAG_26: U13.a2, U33.6 (QG)
/EN_JTAG_27: U14.c2, U34.2 (QC)
/EN_JTAG_28: U14.a2, U34.6 (QG)
/EN_JTAG_29: U15.c2, U35.2 (QC)
/EN_JTAG_30: U15.a2, U35.6 (QG)
/EN_JTAG_31: U16.c2, U36.2 (QC)
/EN_JTAG_32: U16.a2, U36.6 (QG)
/EN_JTAG_33: U17.c2, U37.2 (QC)
/EN_JTAG_34: U17.a2, U37.6 (QG)
/EN_JTAG_36: U18.a2, U38.6 (QG)
/EN_JTAG_37: U19.c2, U39.2 (QC)
/EN_JTAG_39: U20.c2, U40.2 (QC)
/EN_PWR_1: U1.c4, U21.15 (QA)
/EN_PWR_2: U1.a4, U21.4 (QE)
/EN_PWR_3: U2.c4, U22.15 (QA)
/EN_PWR_4: U2.a4, U22.4 (QE)
/EN_PWR_5: U3.c4, U23.15 (QA)
/EN_PWR_6: U3.a4, U23.4 (QE)
/EN_PWR_7: U4.c4, U24.15 (QA)
/EN_PWR_8: U4.a4, U24.4 (QE)
/EN_PWR_9: U5.c4, U25.15 (QA)
/EN_PWR_10: U5.a4, U25.4 (QE)
/EN_PWR_11: U6.c4, U26.15 (QA)
/EN_PWR_12: U6.a4, U26.4 (QE)
/EN_PWR_13: U7.c4, U27.15 (QA)
/EN_PWR_14: U7.a4, U27.4 (QE)
/EN_PWR_15: U8.c4, U28.15 (QA)
/EN_PWR_16: U8.a4, U28.4 (QE)
/EN_PWR_17: U9.c4, U29.15 (QA)
/EN_PWR_18: U9.a4, U29.4 (QE)
/EN_PWR_19: U10.c4, U30.15 (QA)
/EN_PWR_20: U10.a4, U30.4 (QE)
/EN_PWR_21: U11.c4, U31.15 (QA)
/EN_PWR_22: U11.a4, U31.4 (QE)
/EN_PWR_23: U12.c4, U32.15 (QA)
/EN_PWR_24: U12.a4, U32.4 (QE)
/EN_PWR_25: U13.c4, U33.15 (QA)
/EN_PWR_26: U13.a4, U33.4 (QE)
/EN_PWR_27: U14.c4, U34.15 (QA)
/EN_PWR_28: U14.a4, U34.4 (QE)
/EN_PWR_29: U15.c4, U35.15 (QA)
/EN_PWR_30: U15.a4, U35.4 (QE)
/EN_PWR_31: U16.c4, U36.15 (QA)
/EN_PWR_32: U16.a4, U36.4 (QE)
/EN_PWR_33: U17.c4, U37.15 (QA)
/EN_PWR_34: U17.a4, U37.4 (QE)
/EN_PWR_37: U19.c4, U39.15 (QA)
/EN_PWR_39: U20.c4, U40.15 (QA)
/PGEC: U1.a8, U1.b8, U1.c8, U2.a8, U2.b8, U2.c8, U3.a8, U3.b8, U3.c8, U4.a8, U4.b8, U4.c8, U5.a8, U5.b8, U5.c8, U6.a8, U6.b8, U6.c8, U7.a8, U7.b8, U7.c8, U8.a8, U8.b8, U8.c8, U9.a8, U9.b8, U9.c8, U10.a8, U10.b8, U10.c8, U11.a8, U11.b8, U11.c8, U12.a8, U12.b8, U12.c8, U13.a8, U13.b8, U13.c8, U14.a8, U14.b8, U14.c8, U15.a8, U15.b8, U15.c8, U16.a8, U16.b8, U16.c8, U17.a8, U17.b8, U17.c8, U18.a8, U18.b8, U18.c8, U19.c8, U20.c8
/PGED: U1.a7, U1.b7, U1.c7, U2.a7, U2.b7, U2.c7, U3.a7, U3.b7, U3.c7, U4.a7, U4.b7, U4.c7, U5.a7, U5.b7, U5.c7, U6.a7, U6.b7, U6.c7, U7.a7, U7.b7, U7.c7, U8.a7, U8.b7, U8.c7, U9.a7, U9.b7, U9.c7, U10.a7, U10.b7, U10.c7, U11.a7, U11.b7, U11.c7, U12.a7, U12.b7, U12.c7, U13.a7, U13.b7, U13.c7, U14.a7, U14.b7, U14.c7, U15.a7, U15.b7, U15.c7, U16.a7, U16.b7, U16.c7, U17.a7, U17.b7, U17.c7, U18.a7, U18.b7, U18.c7, U19.c7, U20.c7
/SHIFT_CLK_IN: RN1.2 (R2.1), U18.c3, U20.a3, U21.11 (SRCLK), U22.11 (SRCLK), U23.11 (SRCLK), U24.11 (SRCLK), U25.11 (SRCLK), U26.11 (SRCLK), U27.11 (SRCLK), U28.11 (SRCLK), U29.11 (SRCLK), U30.11 (SRCLK), U31.11 (SRCLK), U32.11 (SRCLK), U33.11 (SRCLK), U34.11 (SRCLK), U35.11 (SRCLK), U36.11 (SRCLK), U37.11 (SRCLK), U38.11 (SRCLK), U39.11 (SRCLK), U40.11 (SRCLK)
/SPARE_1: U1.c1, U21.3 (QD)
/SPARE_2: U1.a1, U21.7 (QH)
/SPARE_3: U2.c1, U22.3 (QD)
/SPARE_4: U2.a1, U22.7 (QH)
/SPARE_5: U3.c1, U23.3 (QD)
/SPARE_6: U3.a1, U23.7 (QH)
/SPARE_7: U4.c1, U24.3 (QD)
/SPARE_8: U4.a1, U24.7 (QH)
/SPARE_9: U5.c1, U25.3 (QD)
/SPARE_10: U5.a1, U25.7 (QH)
/SPARE_11: U6.c1, U26.3 (QD)
/SPARE_12: U6.a1, U26.7 (QH)
/SPARE_13: U7.c1, U27.3 (QD)
/SPARE_14: U7.a1, U27.7 (QH)
/SPARE_15: U8.c1, U28.3 (QD)
/SPARE_16: U8.a1, U28.7 (QH)
/SPARE_17: U9.c1, U29.3 (QD)
/SPARE_18: U9.a1, U29.7 (QH)
/SPARE_19: U10.c1, U30.3 (QD)
/SPARE_20: U10.a1, U30.7 (QH)
/SPARE_21: U11.c1, U31.3 (QD)
/SPARE_22: U11.a1, U31.7 (QH)
/SPARE_23: U12.c1, U32.3 (QD)
/SPARE_24: U12.a1, U32.7 (QH)
/SPARE_25: U13.c1, U33.3 (QD)
/SPARE_26: U13.a1, U33.7 (QH)
/SPARE_27: U14.c1, U34.3 (QD)
/SPARE_28: U14.a1, U34.7 (QH)
/SPARE_29: U15.c1, U35.3 (QD)
/SPARE_30: U15.a1, U35.7 (QH)
/SPARE_31: U16.c1, U36.3 (QD)
/SPARE_32: U16.a1, U36.7 (QH)
/SPARE_33: U17.c1, U37.3 (QD)
/SPARE_34: U17.a1, U37.7 (QH)
/SPARE_37: U19.c1, U39.3 (QD)
/SPARE_39: U20.c1, U40.3 (QD)
/STORAGE_CLK: RN1.3 (R3.1), U18.c2, U20.a2, U21.12 (RCLK), U22.12 (RCLK), U23.12 (RCLK), U24.12 (RCLK), U25.12 (RCLK), U26.12 (RCLK), U27.12 (RCLK), U28.12 (RCLK), U29.12 (RCLK), U30.12 (RCLK), U31.12 (RCLK), U32.12 (RCLK), U33.12 (RCLK), U34.12 (RCLK), U35.12 (RCLK), U36.12 (RCLK), U37.12 (RCLK), U38.12 (RCLK), U39.12 (RCLK), U40.12 (RCLK)
/TARGET_RX: U1.a6, U1.b6, U1.c6, U2.a6, U2.b6, U2.c6, U3.a6, U3.b6, U3.c6, U4.a6, U4.b6, U4.c6, U5.a6, U5.b6, U5.c6, U6.a6, U6.b6, U6.c6, U7.a6, U7.b6, U7.c6, U8.a6, U8.b6, U8.c6, U9.a6, U9.b6, U9.c6, U10.a6, U10.b6, U10.c6, U11.a6, U11.b6, U11.c6, U12.a6, U12.b6, U12.c6, U13.a6, U13.b6, U13.c6, U14.a6, U14.b6, U14.c6, U15.a6, U15.b6, U15.c6, U16.a6, U16.b6, U16.c6, U17.a6, U17.b6, U17.c6, U18.a6, U18.b6, U18.c6, U19.c6, U20.c6
/TARGET_TX: U1.a5, U1.b5, U1.c5, U2.a5, U2.b5, U2.c5, U3.a5, U3.b5, U3.c5, U4.a5, U4.b5, U4.c5, U5.a5, U5.b5, U5.c5, U6.a5, U6.b5, U6.c5, U7.a5, U7.b5, U7.c5, U8.a5, U8.b5, U8.c5, U9.a5, U9.b5, U9.c5, U10.a5, U10.b5, U10.c5, U11.a5, U11.b5, U11.c5, U12.a5, U12.b5, U12.c5, U13.a5, U13.b5, U13.c5, U14.a5, U14.b5, U14.c5, U15.a5, U15.b5, U15.c5, U16.a5, U16.b5, U16.c5, U17.a5, U17.b5, U17.c5, U18.a5, U18.b5, U18.c5, U19.c5, U20.c5
/TCK: U1.a10, U1.b10, U1.c10, U2.a10, U2.b10, U2.c10, U3.a10, U3.b10, U3.c10, U4.a10, U4.b10, U4.c10, U5.a10, U5.b10, U5.c10, U6.a10, U6.b10, U6.c10, U7.a10, U7.b10, U7.c10, U8.a10, U8.b10, U8.c10, U9.a10, U9.b10, U9.c10, U10.a10, U10.b10, U10.c10, U11.a10, U11.b10, U11.c10, U12.a10, U12.b10, U12.c10, U13.a10, U13.b10, U13.c10, U14.a10, U14.b10, U14.c10, U15.a10, U15.b10, U15.c10, U16.a10, U16.b10, U16.c10, U17.a10, U17.b10, U17.c10, U18.a10, U18.b10, U18.c10, U19.c10, U20.c10
/TDI: U1.a13, U1.b13, U1.c13, U2.a13, U2.b13, U2.c13, U3.a13, U3.b13, U3.c13, U4.a13, U4.b13, U4.c13, U5.a13, U5.b13, U5.c13, U6.a13, U6.b13, U6.c13, U7.a13, U7.b13, U7.c13, U8.a13, U8.b13, U8.c13, U9.a13, U9.b13, U9.c13, U10.a13, U10.b13, U10.c13, U11.a13, U11.b13, U11.c13, U12.a13, U12.b13, U12.c13, U13.a13, U13.b13, U13.c13, U14.a13, U14.b13, U14.c13, U15.a13, U15.b13, U15.c13, U16.a13, U16.b13, U16.c13, U17.a13, U17.b13, U17.c13, U18.a13, U18.b13, U18.c13, U19.c13, U20.c13
/TDO: U1.a12, U1.b12, U1.c12, U2.a12, U2.b12, U2.c12, U3.a12, U3.b12, U3.c12, U4.a12, U4.b12, U4.c12, U5.a12, U5.b12, U5.c12, U6.a12, U6.b12, U6.c12, U7.a12, U7.b12, U7.c12, U8.a12, U8.b12, U8.c12, U9.a12, U9.b12, U9.c12, U10.a12, U10.b12, U10.c12, U11.a12, U11.b12, U11.c12, U12.a12, U12.b12, U12.c12, U13.a12, U13.b12, U13.c12, U14.a12, U14.b12, U14.c12, U15.a12, U15.b12, U15.c12, U16.a12, U16.b12, U16.c12, U17.a12, U17.b12, U17.c12, U18.a12, U18.b12, U18.c12, U19.c12, U20.c12
/TMS: U1.a11, U1.b11, U1.c11, U2.a11, U2.b11, U2.c11, U3.a11, U3.b11, U3.c11, U4.a11, U4.b11, U4.c11, U5.a11, U5.b11, U5.c11, U6.a11, U6.b11, U6.c11, U7.a11, U7.b11, U7.c11, U8.a11, U8.b11, U8.c11, U9.a11, U9.b11, U9.c11, U10.a11, U10.b11, U10.c11, U11.a11, U11.b11, U11.c11, U12.a11, U12.b11, U12.c11, U13.a11, U13.b11, U13.c11, U14.a11, U14.b11, U14.c11, U15.a11, U15.b11, U15.c11, U16.a11, U16.b11, U16.c11, U17.a11, U17.b11, U17.c11, U18.a11, U18.b11, U18.c11, U19.c11, U20.c11
/~MASTER_RST: RN1.1 (R1.1), U18.a4, U20.a5, U21.10 (~SRCLR), U22.10 (~SRCLR), U23.10 (~SRCLR), U24.10 (~SRCLR), U25.10 (~SRCLR), U26.10 (~SRCLR), U27.10 (~SRCLR), U28.10 (~SRCLR), U29.10 (~SRCLR), U30.10 (~SRCLR), U31.10 (~SRCLR), U32.10 (~SRCLR), U33.10 (~SRCLR), U34.10 (~SRCLR), U35.10 (~SRCLR), U36.10 (~SRCLR), U37.10 (~SRCLR), U38.10 (~SRCLR), U39.10 (~SRCLR), U40.10 (~SRCLR)
/~MCLR: U1.a9, U1.b9, U1.c9, U2.a9, U2.b9, U2.c9, U3.a9, U3.b9, U3.c9, U4.a9, U4.b9, U4.c9, U5.a9, U5.b9, U5.c9, U6.a9, U6.b9, U6.c9, U7.a9, U7.b9, U7.c9, U8.a9, U8.b9, U8.c9, U9.a9, U9.b9, U9.c9, U10.a9, U10.b9, U10.c9, U11.a9, U11.b9, U11.c9, U12.a9, U12.b9, U12.c9, U13.a9, U13.b9, U13.c9, U14.a9, U14.b9, U14.c9, U15.a9, U15.b9, U15.c9, U16.a9, U16.b9, U16.c9, U17.a9, U17.b9, U17.c9, U18.a9, U18.b9, U18.c9, U19.c9, U20.c9
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

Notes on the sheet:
Slot 1
Slot 2
Slot 3
Slot 4
Slot 5 (UNUSED)
Slot 6
Slot 7
Slot 8
Slot 9
Slot 10
Slot 11
Slot 12
Slot 13
Slot 14
Slot 15
Slot 16 (UNUSED)
Slot 17
Slot 18
Slot 19
Slot 20
RPi or similar
USB board?
Integrated ICSP/JTAG programmer
External ICSP/JTAG programmer (2x!)

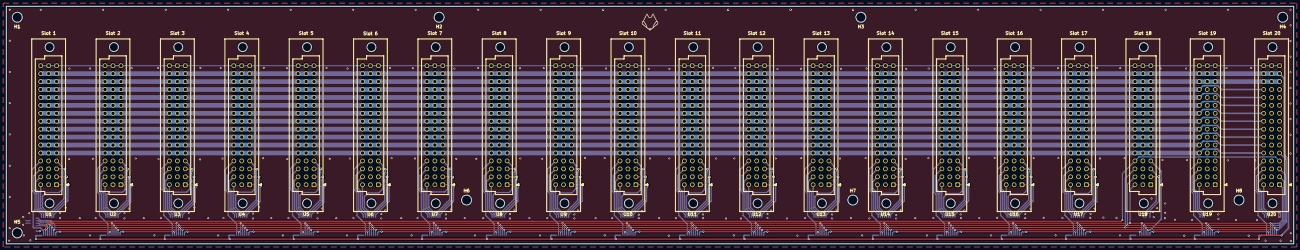
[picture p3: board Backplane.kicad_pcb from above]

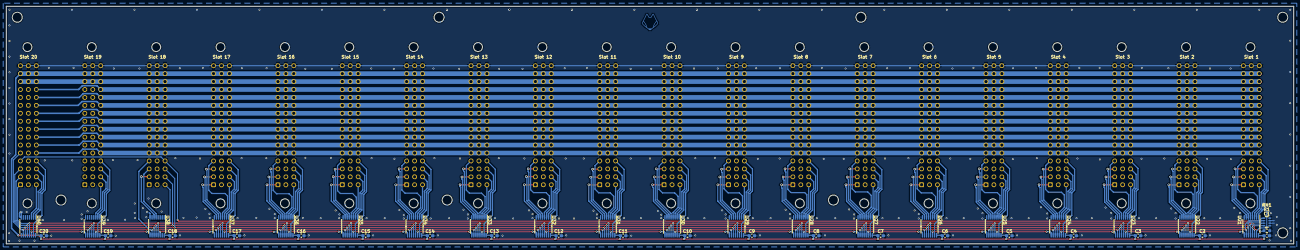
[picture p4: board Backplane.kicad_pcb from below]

Board: 2 copper layers, 412.0 x 76.0 mm, 73 parts (45 on the bottom side), 182 nets.

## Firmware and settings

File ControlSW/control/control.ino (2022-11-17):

// Pins for controlling the 74HC595 registers
#define CTRL_PIN_DIN  2 // D2
#define CTRL_PIN_SHCP 3 // D3
#define CTRL_PIN_STCP 4 // D4
#define CTRL_PIN_nOE  5 // D5
// Input pin from the selected board. Inverted input, needs pull-up
#define CTRL_PIN_SPARE_IN  6  // D6
// Our output, extra
#define PIN_SPARE_OUT 8 // D8

// We're setting pins on the 595 registers. 8 pins per slot => 2 banks with 4 pins per bank
// POWER pins are ACTIVE HIGH
// INTERFACE pins are ACTIVE LOW
// SPARE pin is generic output
// QA/D0 && QE/D4 == POWER ENABLE (active HIGH)
// QB/D1 && QF/D5 == ICSP ENABLE (active LOW)
// QC/D2 && QG/D6 == JTAG ENABLE (active LOW)
// QD/D3 && QH/D7 == generic output
// First bank is QA/D0 to QD/D3, second bank is QE/D4 to QH/D7
#define BIT_PWR   0x01
#define BIT_ICSP  0x02
#define BIT_JTAG  0x04
#define BIT_PIN 0x08

uint8_t currentInShift[20] = {0b01100110}; // Memset in setup
uint8_t currentAtOut[20] = {0b01100110};

void sendByte(uint8_t data){
  // Data is send MSB first
  // Clock (SHCP) is IDLE LOW, Data is latched on rising edge

  for (int counter=7; counter >=0; counter--){
    int theBit = (data >> counter) & 0x01;
    digitalWrite(CTRL_PIN_DIN, theBit);
    delayMicroseconds(10);
    digitalWrite(CTRL_PIN_SHCP, HIGH);
    delayMicroseconds(10);
    digitalWrite(CTRL_PIN_SHCP, LOW);
    delayMicroseconds(10);
  }

}

void updateEverything(){
  for (int counter = sizeof(currentInShift)-1; counter>=0; counter--){
    sendByte(currentInShift[counter]);
  }
  transferDataToOutput();
}

void transferDataToOutput(){
  // Data is transfered to output on rising edge of STCP
  for (int counter=0; counter < sizeof(currentAtOut); counter++){
   currentAtOut[counter] = currentInShift[counter];
  }
  digitalWrite(CTRL_PIN_STCP, HIGH);
  delayMicroseconds(10);
  digitalWrite(CTRL_PIN_STCP, LOW);
  delayMicroseconds(10);
}

void setOutput(int val){
  // Inverted logic
  if (val){
    digitalWrite(CTRL_PIN_nOE, LOW);
    Serial.println("Turning outputs ON");
  }
  else{
    digitalWrite(CTRL_PIN_nOE, HIGH);
    Serial.println("Turning outputs OFF");
  }
}

void setup() {
  // Setup pin modes
  pinMode(CTRL_PIN_DIN, OUTPUT);
  pinMode(CTRL_PIN_SHCP, OUTPUT);
  pinMode(CTRL_PIN_STCP, OUTPUT);
  pinMode(CTRL_PIN_nOE, OUTPUT);
  
  pinMode(CTRL_PIN_SPARE_IN, INPUT_PULLUP);
  
  pinMode(PIN_SPARE_OUT, OUTPUT);

  // Also set outputs to default
  digitalWrite(CTRL_PIN_DIN, LOW);
  digitalWrite(CTRL_PIN_SHCP, LOW);
  digitalWrite(CTRL_PIN_STCP, LOW);
  digitalWrite(CTRL_PIN_nOE, HIGH);

  digitalWrite(PIN_SPARE_OUT, HIGH);

  Serial.begin(9600);

  for (int counter=0; counter < sizeof(currentAtOut); counter++){
   currentAtOut[counter] = 0b01100110;
   currentInShift[counter] = 0b01100110;
  }

  updateEverything();
  transferDataToOutput();
  setOutput(1);
  
}

void loop() {
  int done = 0;
  String tempString = "";

  int numConverted = 0;
  char argOne[16];
  uint8_t argTwo;
  char argThree[16];
  char argFour[16];
  char argFive[16];


  
  
  while (!done){
    if (Serial.available()>0){
       char t = Serial.read();
       if (t == '\n' || t == '\r'){
        //tempString = tempString + t;
        done = 1;
       }
       else{
        tempString = tempString + t;
       }
    }
  }


  tempString.toUpperCase();  // Don't care about case
  tempString.trim();                  // Remove whitespaces etc.

  if (tempString.equals("HELP")){
    Serial.println("Simple backplane controller");
    Serial.println("---------------------------");
    Serial.println("SET [SLOT] [BANK] [WHAT] [ON/OFF]");
    Serial.println("-> SLOT == 1 to 20");
    Serial.println("-> BANK == A or B");
    Serial.println("-> WHAT == PWR, ICSP, JTAG, PIN");
    Serial.println("-> ON == Asserted, OFF == Deasserted (polarities are taken care of)");
    Serial.println("GET [SLOT] [BANK] [WHAT]");
    Serial.println("See above for what is what.");
    Serial.println("");
  }
  
  Serial.println(tempString);
  numConverted = sscanf(tempString.c_str(), "%s %d %s %s %s",
                       argOne, &argTwo, argThree, argFour, argFive);


  if ((String(argOne) == "SET") && (numConverted == 5)){
    if (argTwo < 1 || argTwo > 20){
      Serial.println("NACK");
    }
    else if ((String(argThree) != "A") && (String(argThree) != "B")){
      Serial.println("NACK");
    }
    else if ((String(argFour) != "PWR") && (String(argFour) != "ICSP")
        && (String(argFour) != "JTAG") && (String(argFour) != "PIN")){
      Serial.println("NACK");
    } 
    else if ((String(argFive) != "ON") && (String(argFive) != "OFF")){
      Serial.println("NACK");
    }
    else{

      // Parse data
      uint8_t slot = argTwo - 1;
      
      uint8_t bank = 0; // A == default
      if (String(argThree) == "B"){
        bank = 4;
      }

      uint8_t onOff = 0; // OFF default
      if (String(argFive) == "ON"){
        onOff = 1;
      }        

      uint8_t bit = BIT_PWR;  // PWR == default
      if (String(argFour) == "ICSP"){
        bit = BIT_ICSP;
      }
      else if (String(argFour) == "JTAG"){
        bit = BIT_JTAG;
      }
      else if (String(argFour) == "PIN"){
        bit = BIT_PIN;
      }
      
      // PWR and SPARE bits get SET ON as they are. ICSP and JTAG are INVERTED
      // To set, PWR and SPARE; shift[slot] = shift[slot] | (bit << bank)
      // To clr, PWR and SPARE; shift[slot] = shift[slot] & (~(bit << bank))
      // JTAG and ICSP are inverted.    
      if (onOff){
        if (bit == BIT_PWR || bit == BIT_PIN){
          currentInShift[slot] = currentInShift[slot] | (bit << bank);
        }
        else{
          currentInShift[slot] = currentInShift[slot] & (~(bit << bank));
        }
      }
      else{
        if (bit == BIT_PWR || bit == BIT_PIN){
          currentInShift[slot] = currentInShift[slot] & (~(bit << bank));
        }
        else{
          currentInShift[slot] = currentInShift[slot] | (bit << bank);
        }
      }

      updateEverything();
      transferDataToOutput();
      setOutput(1);

    }
  }

  else if ((String(argOne) == "GET") && (numConverted == 4)){
    if (argTwo < 1 || argTwo > 20){
      Serial.println("NACK");
    }
    else if ((String(argThree) != "A") && (String(argThree) != "B")){
      Serial.println("NACK");
    }
    else if ((String(argFour) != "PWR") && (String(argFour) != "ICSP")
        && (String(argFour) != "JTAG") && (String(argFour) != "PIN")){
      Serial.println("NACK");
    }
    else{
            // Parse data
      uint8_t slot = argTwo - 1;
      
      uint8_t bank = 0; // A == default
      if (String(argThree) == "B"){
        bank = 4;
      }

      uint8_t bit = BIT_PWR;  // PWR == default
      if (String(argFour) == "ICSP"){
        bit = BIT_ICSP;
      }
      else if (String(argFour) == "JTAG"){
        bit = BIT_JTAG;
      }
      else if (String(argFour) == "PIN"){
        bit = BIT_PIN;
      }

      uint8_t info = currentInShift[slot] & (bit >> bank);
      if (info){
        info = 1;
      }
      if (bit == BIT_ICSP || bit == BIT_JTAG){
        info = info ^ 0x01;
      }

      Serial.println("ACK");
      Serial.println("VAL: " + String(info));
        
    }
  }
  else{
    Serial.println("NACK");
  }

}

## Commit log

2021-11-29 Belated start
    [All chips comparison.ods, Backplane.kicad_pcb, Backplane.sch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]
2021-11-29 Rotate all connectors on the backplane (measure twice...)
    [Backplane.kicad_pcb, Backplane.sch]
2021-11-30 Mid-work commit. Add README
    [RiserCard.kicad_pcb]
2021-12-05 mid-work commit, preparing the riser card
    [RiserCard.kicad_pcb]
2021-12-05 Mid-work commit. IT's not pretty but it'll work
    [RiserCard.kicad_pcb, RiserCard.sch]
2022-01-02 Mid-work commit. Added notes, figured out what works, etc.
    [Backplane-B_Cu.gbr, Backplane-B_Mask.gbr, Backplane-B_SilkS.gbr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]
2022-01-09 Added comparison of chips, etc.
    [ListOfChips.ods, PinoutComparison_64pin.ods]
2022-01-09 Move and rename
    [RiserCard-B_Cu.gbr, RiserCard-B_Mask.gbr, RiserCard-B_SilkS.gbr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]
2022-01-09 Add Rev2 of Riser Card. LED connection fixed.
    [RiserCard-B_Cu.gbr, RiserCard-B_Mask.gbr, RiserCard-B_SilkS.gbr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]
2022-05-29 Move from one computer to another, commit changes
    [ListOfChips.ods]
2022-05-29 Updte current status
    [ListOfChips.ods]
2022-07-05 Update current status
    [ListOfChips.ods]
2022-11-17 Update to latest state on primary computer
    [Backplane.kicad_pcb, ListOfChips.ods]
